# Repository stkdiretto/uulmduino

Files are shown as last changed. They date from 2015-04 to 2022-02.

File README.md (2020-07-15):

# uulmduino

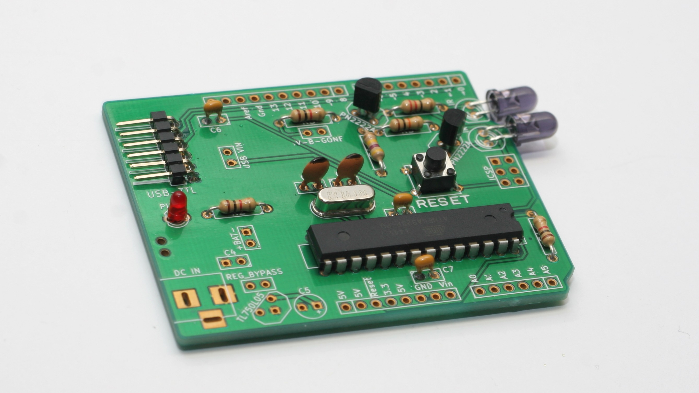
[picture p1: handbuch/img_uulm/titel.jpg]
Yay!


Eine Mischung aus Arduino (besser gesagt dem [Diavolino von Evil Mad Scientist Labs](http://www.evilmadscientist.com/2010/diavolino/)) und der [TV-B-Gone-Version von Ken Shirriff](https://github.com/shirriff/Arduino-TV-B-Gone). Auf Basis des Diavolino und mit Hilfe des [Sparkfun Inventors' Kit](https://www.sparkfun.com/products/12060) von der [Arbeitsgruppe WissenSchaffer](http://www.uni-ulm.de/in/fakultaet/studieninteressierte/wissenschaffer.html) entwickelt für den Girls'Day 2015 an der Uni Ulm.

## Handbuch bauen

Das Handbuch ist [im Ordner "handbuch"](handbuch/) und liegt als Markdown vor. Es kann mit Pandoc nach PDF exportiert werden:

`pandoc anleitung.md -o anleitung.pdf --latex-engine=xelatex --variable geometry="a5paper" --variable mainfont="Droid Sans"`

Wer das Projekt nachmachen möchte, findet im handbuch-Ordner auch eine skizzenhafte Anleitung, was hinter den Kulissen passieren muss. Pull-Requests zur Verbesserung sind gerne gesehen!

## Dankeschöns

 * Leiterplattentechnik der Uni Ulm für die gute Beratung und die Platinenfertigung
 * Maria Aufheimer, Robien Baldrich, Dominic Meißner, David-1 Schmid für Bugfixing und Input
 * Juliane Wessalowski für den Betatest
 * Alle Beitragenden, deren Basismaterial unter Freier Lizenz wir verwenden durften!

## Changelog
 * 2015-04-22 Erste Version
 * 2015-04-22 Übersetzte Experimente aus dem SIK hinzugefügt
 * 2015-04-22 KiCad-Quellen hinzugefuegt
 * 2015-08-26 Revision 2 mit umfangreicherererer KiCad-Quellenlage und einigen gefixten Fehlern. Noch nicht praxiserprobt!
 * 2015-11-16 Fehler in rev2 vermerkt und [BOM](bom.md) hinzugefügt, Fehler im Handbuch korrigiert
 * 2016-04-12 Erster Aufschlag einer [Anleitung für KursleiterInnen](handbuch/fuer%20kursleiter_innen.md)

## Bekannte Fehler (Revision 2)
 * Bei allen Transistoren sind B und E vertauscht :(

## Bekannte Fehler (Revision 1, veraltet)
 * IR-Sender ist auf dem Board mit Pin 9 verbunden → Sollte Pin 10 sein (Fixed in rev2)
 * DC-In-Buchse hat Masse auf dem mittleren Pin, sollte eigentlich andersherum sein (Fixed in rev2)
 * Bohrlöcher für die Zugentlastung der Batteriekastenzuleitungen sind zu klein (Fixed in rev2)
 * Beschriftungen könnten besser sein (Sort of fixed in rev2)
 * KiCad-Files sind sehr unorganisiert (Sort of fixed in rev2)

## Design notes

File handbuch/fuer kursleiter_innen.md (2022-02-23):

# uulmduino – Handbuch für Kursleiter_innen

Titelbild

Ein Free-Hardware+Software-Projekt nicht nur für Jugendliche.  

Basierend auf dem Diavolino von Evil Mad Scientist  
http://www.evilmadscientist.com/go/diavolino

Bausatzversion 2
Handbuch für Kursleiter_innen, passend zum Handbuch v. 0.21, 2015-11-25

# Vorbereitung

Cool, dass Du unser Projekt bei Dir umsetzen möchtest! :) Für die Umsetzung bei Dir brauchst Du die folgenden Dinge:

 * Platinen für alle Teilnehmer_innen, und am besten mindestens noch eine für Dich selbst zum vorher selbst ausprobieren. Falls Du die nicht selber mit den Design Files in diesem Repository herstellen willst, kannst Du auch welche von uns bekommen!
 * Für jedes Exemplar die notwendigen Bauteile, die [in der BOM aufgelistet sind](../BOM.md)
 * Ausreichend viele Lötarbeitsplätze (idealerweise pro Teilnehmer_in, ggf. auch ein Platz pro zwei Personen) mit
  * Lötkolben
  * Lötzinn
  * Entlötpumpe
  * Falls gewünscht: Flussmittel
  * Ausreichend Beleuchtung
  * ggf. Holzbrettchen als Lötunterlage
 * FTDI-232-Adapter zum Programmieren, samt USB-Kabel. Die gibt es in „Original“ für je 15 EUR bei Watterott, exp-tech und Co., oder als Clones für ca. 5 EUR von ebay – bei letzteren aber mit unklarer Funktionsgarantie. Im Idealfall hast Du ebensoviele FTDI-Adapter wie Teilnehmer\*innen.
 * Einen In-System-Programmer oder zwei klassische Arduinos, um die Atmegas vorher zu flashen
 * Ausreichend viele Rechner/Laptops mit der Arduino IDE, den Beispielprogrammen von Sparkfun und dem TV-B-Gone-Sketch
  * Falls Du Windows verwendest, musst du vorher den FTDI-Treiber installieren

## Atmegas flashen

*Bevor* die Bausätze verlötet werden, solltest du auf allen Microcontrollern den Arduino-Bootloader installieren. 

Wenn du ohnehin „klassische“ Arduinos herumliegen hast, kannst du einen davon als ISP verwenden, ihn per Drahtbrücken mit einem zweiten Arduino-Board verbinden und dort die „frischen“ Chips sockeln und flashen. Klingt kompliziert, geht aber recht simpel. [Eine Anleitung findest du hier](https://www.arduino.cc/en/Tutorial/ArduinoISP). Falls du keinen Arduino mit Wechselsockel hast, in den du die frischen Chips einsetzen kannst, geht das auch auf einem Steckbrett (siehe Anleitung).

Die andere (ggf. bei vielen zu flashenden Controllern etwas schnellere) Variante ist ein klassischer ISP. Der [usbasp](http://www.fischl.de/usbasp/) ist günstig zu haben, als China-Clon von ebay sogar für deutlich unter 5 EUR. In dem Fall würde ich dem Erfinder dann aber noch per PayPal ein paar Euro in den Hut werfen wollen ;)  
Mit dem usbasp lässt sich mittels 10-auf-6-Pin-Adapterkabel der Controller auch flashen, wenn er schon verlötet ist – dazu einfach die sechspolige Headerleiste auf der Platine bestücken, oder einen [Pogo-Pin-Adapter](http://www.exp-tech.de/isp-pogo-adapter) auf die Kontakte aufdrücken. Empfehlenswerter ist aber, die Controller vorher in ein passendes Evaluationsboard zu stecken und zu flashen – früher war das Pollin-Evaluationsboard für 15 EUR das Mittel der Wahl, heutzutage gibt es mit dem [aTeVaL](https://www.ehajo.de/aTeVaL-v2.0-Microchip-AVR-Evaluationsboard/200.018) für ca 30 EUR jedoch eine praktischere Lösung, bei der der USB-ISP-Adapter bereits integriert ist.

Auf [Sparkfun ist der Flash-Prozess mit einem USB-Adapter](https://learn.sparkfun.com/tutorials/installing-an-arduino-bootloader) ebenfalls gut beschrieben.

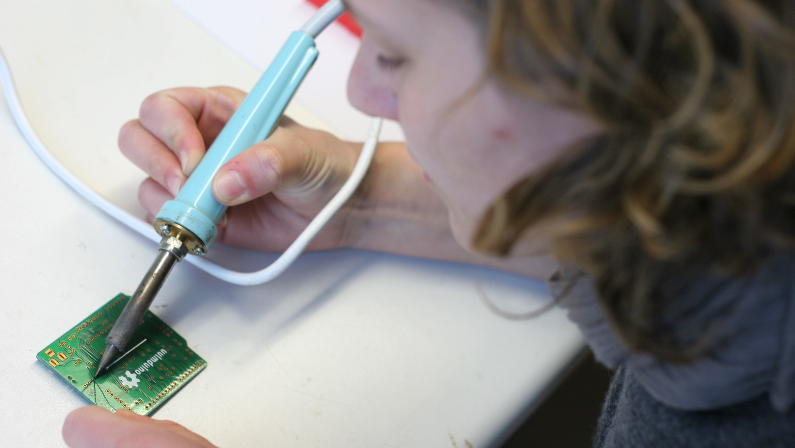
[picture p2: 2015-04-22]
handbuch/img_uulm/loeten.jpg

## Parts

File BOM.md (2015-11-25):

# Bill of Materials

| Name | Anzahl | Reichelt-Artikelnummer | Preis Reichelt | Gesamtpreis |
|---|---|---|---|---|
| Atmega 328 PU | 1 | ATMEGA 328P-PU | 3,15 | 3,15 |
| LED 3mm rot | 1 | LED 3MM ST RT | 0,09 | 0,09 |
| Quarz 16 MHz | 1 | 16,0000-HC49U-S | 0,21 | 0,21 |
| Header, 6 Pins | 1 | MPE 094-1-006 | 0,23 | 0,23 |
| Batteriekasten 3 AAA | 1 für Batteriebetrieb | HALTER 3XAAAK | 0,72 | 0,72 |
| Widerstand 10kΩ | 1 | METALL 10,0K | 0,082 | 0,082 |
| Widerstand 22Ω | 1 | 1/4W 22 | 0,103 | 0,103 |
| Widerstand 470kΩ | 1 | 1/4W 470K | 0,103 | 0,103 |
| Reset-Taster | 1 | TASTER 9302 | 0,11 | 0,11 |
| Transistor PN 2222 A | 2 | PN 2222A | 0,08 | 0,16 |
| IR-LED LD 271 | 2 | LD 271 | 0,42 | 0,84 |
| Keramikkondensator 18P RM 2,5mm  | 2 | KERKO 18P | 0,06 | 0,12 |
| Keramikkondensator 100N RM 2,5mm | 3 | X7R-2,5 100N | 0,05 | 0,15 |
| Header, 8 Pins | 3 | MPE 094-1-008 | 0,23 | 0,69 |
| Widerstand 1kΩ | 3 | 1/4W 1,0K | 0,103 | 0,309 |
| Jumper, RM 2,5mm | 2 | JUMPER 2,54 RT | 0,05 | 0,10 |

Zusätzlich pro 6 Platinen:
 * SL 1X40W 2,54 (0,32 EUR)

Zusätzlich pro 25 Platinen:
 * MPE 087-1-050 (0,87 EUR)

**Batterien nicht vergessen! (3 AAA)** z.B. GP AL40 AAA, 40 Stück für 10,60 EUR. Akkus funktionieren leider nicht.

# Gesamt

7,17 EUR plus 1/6 0,32 EUR plus 1/25 0,87 EUR plus 3/40 10,60 EUR ;) – Platinenkosten etwa 1,25 EUR  
Macht gesamt rund **8,06 EUR** bzw. **9,31 EUR** inkl. Platine.

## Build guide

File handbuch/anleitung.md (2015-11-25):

# uulmduino

Titelbild

Ein Free-Hardware+Software-Projekt für den Girls'Day 2015 an der Universität Ulm.  

Basierend auf dem Diavolino von Evil Mad Scientist  
http://www.evilmadscientist.com/go/diavolino

Bausatzversion 2
Handbuch v. 0.21, 2015-11-25

# Was ist was?

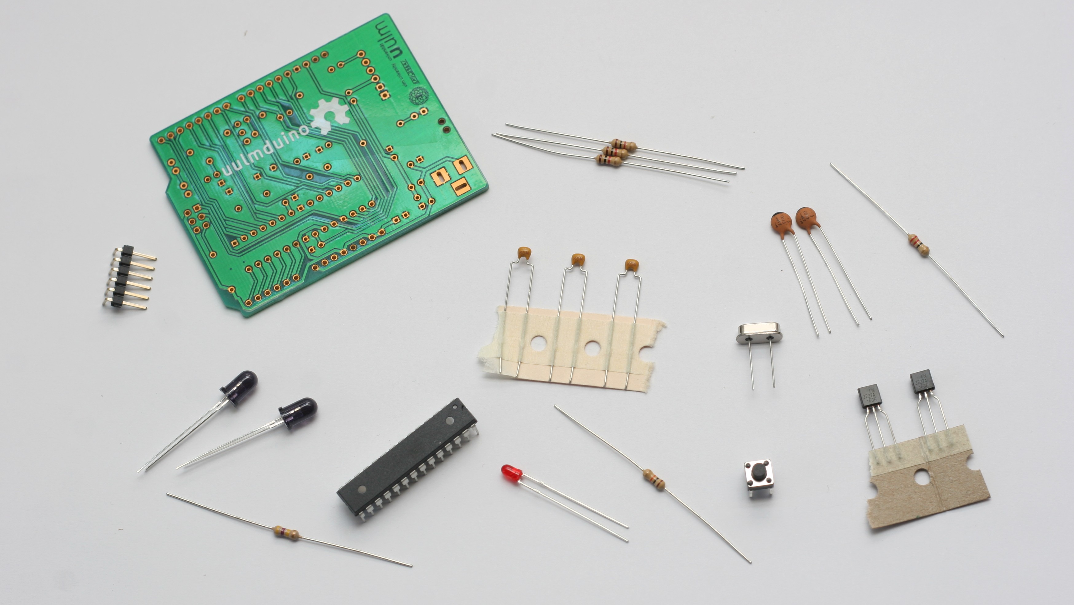
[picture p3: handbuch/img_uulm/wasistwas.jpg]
Was ist was?


 1. Platine
 2. Kurzanleitung (nicht abgebildet)
 3. 1kΩ-Widerstände,¼ Watt (3 Stück)
 4. 10kΩ-Widerstand, ¼ Watt
 5. 18pF-Kondensatoren (2 Stück) (Schwarzer Streifen!)
 6. 1µF-Kondensatoren (3 Stück)
 7. Mikroschalter
 8. LED
 9. Quarz
 10. Header
 11. Microcontroller
 12. 22Ω-Widerstand, ¼ Watt
 13. 470kΩ-Widerstand, ¼ Watt
 14. Transistoren PN2222A (2 Stück)
 15. Infrarot-LEDs LD271 (2 Stück)
 16. Batteriekasten 3×AAA (nicht abgebildet)
 17. Header für Arduino-kompatible Shields (nicht abgebildet)

# Optional für zuhause

Diese Teile reichen vollkommen, um einen Universal-Fernsehausknipser (TV-B-Gone) für unterwegs zu bauen. Für die Programmierung und weitere Experimente in diesem Handbuch sind weitere Teile nötig, die wir Dir aufgrund der Kosten leider nicht mitgeben können. Du kannst sie dir aber für wenig Geld online kaufen, falls du zuhause weitermachen möchtest!

## Für die Programmierung…

Der uulmduino ist Arduino-kompatibel, benötigt aber eine Programmierschnittstelle.

### Ein USB-TTL-Kabel

…mit dem FTDI-chip TTL-232R oder einem vergleichbaren Modell. Das ist ein „intelligentes“ Adapterkabel mit einer eingebauten USB-Schnittstelle. Eine Seite wird in Deinen USB-Port eingesteckt, die andere in den uulmduino. Das Kabel ermöglicht Dir, den uulmduino mit der Arduino-Entwicklungsumgebung zu programmieren (http://arduino.cc/).
Alternativ kann uulmduino auch mittels eines AVR-ISP-Programmierers programmiert werden, zum Beispiel dem USBtinyISP.

### Computer, Internetzugang, USB-Port…

Alle Software, die Du benötigen wirst, ist kostenlos erhältlich. Du brauchst nur einen nicht allzu antiquierten Rechner (Mac, Windows oder Linux) und einen Internetzugang, um die Arduino-Software herunterzuladen.

# Tipps fürs Löten

Die meisten Probleme mit Lötbausätzen sind auf unzureichende Lötstellen zurückzuführen. Bevor wir fortfahren, gibt es hier einen Mini-Lötkurs, mit unserer empfohlenen Vorgehensweise, um die einzelnen Bauteile in die Platine einzulöten. Sie ist auf die meisten Teile dieses Bausatzes anwendbar.

## Bauteile auf die Platine einlöten

 0. Biege die Anschlussdrähte der Teile zurecht, falls nötig. (Zum Beispiel diese Widerstände).
 1. Setze jedes Bauteil von oben her an der vorgesehenen Stelle in die Platine ein. Drücke es bündig an die Platine an (Beachte, dass einige Teile in eine bestimmte Richtung eingesetzt werden müssen – zum Beispiel der Chip und die LED)
 2. Falls das Bauteil flexible Anschlussdrähte hat, biege die Drähte vorsichtig nach außen, bis zu einem Winkel von etwa 45°. Das hält das Bautel an seinem Platz fest, während Du es festlötest.
 3. Löte von der Rückseite her einen Anschlussdraht nach dem anderen an die Platine an.
  * Die Lötspitze muss glänzend (verzinnt) sein. Falls sie das nicht ist, schmelze ein wenig frisches Lötzinn an der Spitze an und wische sie auf einem feuchten Schwamm sauber.
  * Halte das Lötzinn an die Verbindung, die Du verlöten möchtest.
  * Halte den Lötkolben für etwa eine Sekunde an die Lötstelle und das Lötzinn. Zähle einfach laut mit: „Eintausendeins“.
  * Das Lötzinn sollte an die Lötstelle anschmelzen und eine glänzende, etwas feucht aussehende Lötstelle hinterlassen. Falls nicht, lass' sie abkühlen und versuche es noch einmal.
 4. Falls das Bauteil lange und/oder biegbare Anschlussdrähtchen hat, schneide den auf der Unterseite überstehenden Draht ab – dicht an der Platine, aber nicht so nahe daran, dass Du in die Platine selbst hineinschneidest.

 1. Einsetzen!
 2. Biegen!
 3. Löten!
 4. Kürzen!

## Wir fangen mit den 1kΩ-Widerständen an (#3)

Alle Widerstände sind mit Farbringchen codiert. Die 1kΩ-Widerstände, die wir jetzt brauchen, haben der Reihe nach die Farbe Braun-Schwarz-Rot (und danach ein goldenes Ringchen). Schau genau hin und verwechsle sie nicht mit dem 10kΩ-Widerstand – der hat ein orangenes statt eines roten Ringchens!

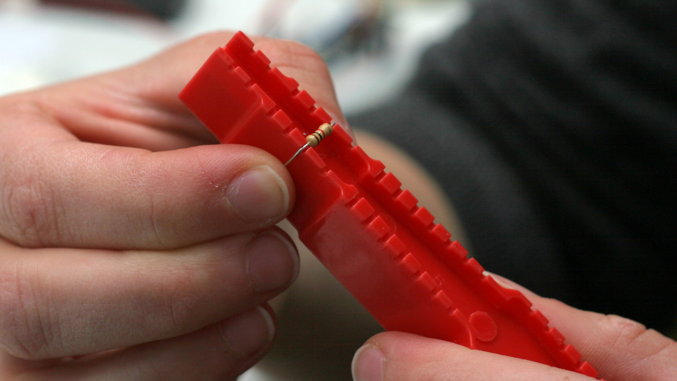
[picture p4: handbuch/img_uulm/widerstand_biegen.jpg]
Zuerst biegst Du die Anschlussdrähte zurecht. Entweder mit einer Biegelehre, oder frei Hand.


Stecke den Widerstand an die mit **R2**, **R3** und **R5** markierten Stellen in die Anschlusslöcher. Wie herum du ihn einsetzt, ist egal – ein Widerstand funktioniert in beide Richtungen.

Plan auf die Platine aufdrücken…

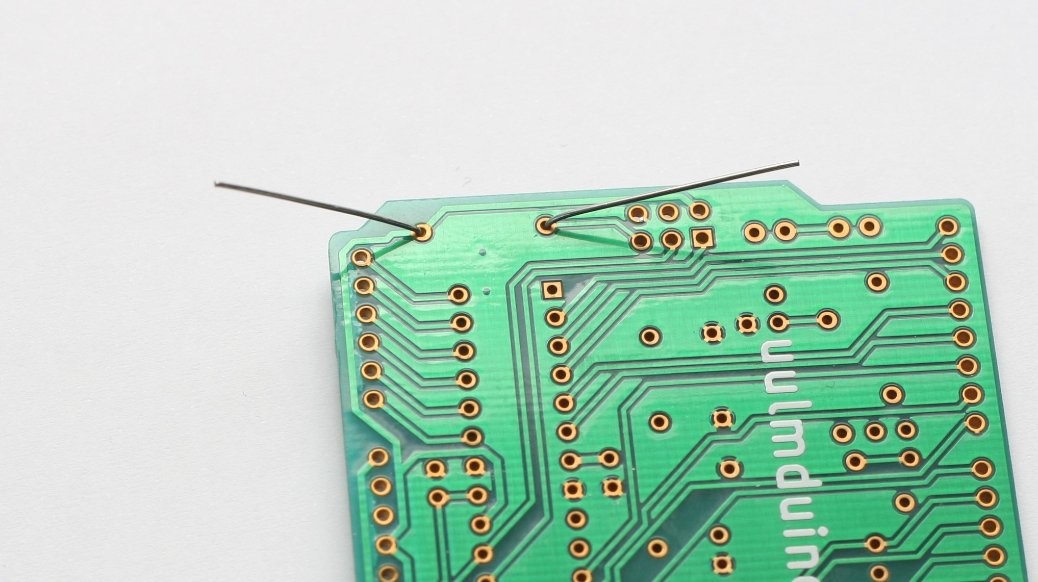
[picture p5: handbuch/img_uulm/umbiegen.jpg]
…und die Anschlussdrähte auf der Unterseite auseinanderbiegen.


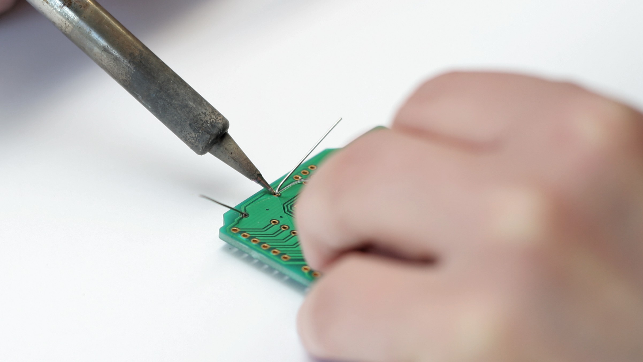
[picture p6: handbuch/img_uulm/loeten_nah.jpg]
Festlöten.


Überprüfe die Lötstellen. Sie sollten glänzend aussehen, und das Lötpad (auf der Platine) und die Beinchen ganz umfließen.

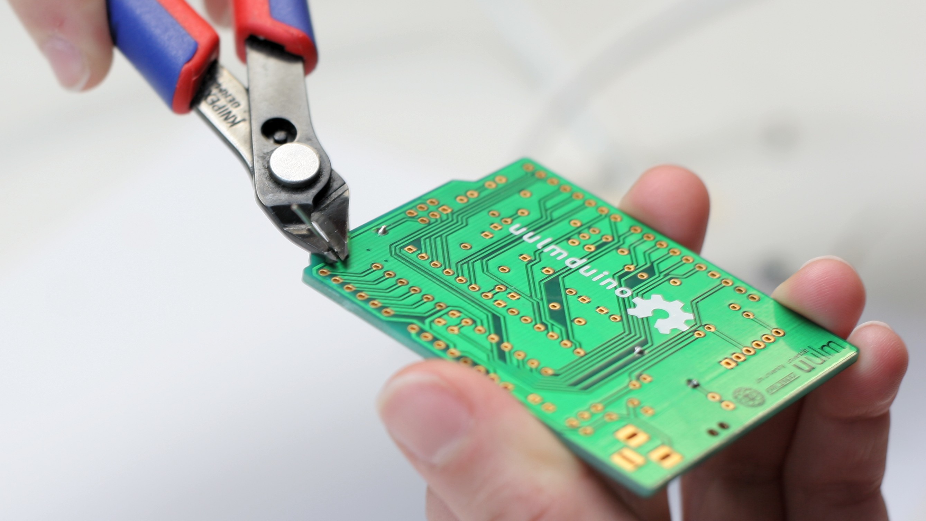
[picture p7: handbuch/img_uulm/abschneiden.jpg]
Überstehende Drähtchen abschneiden.


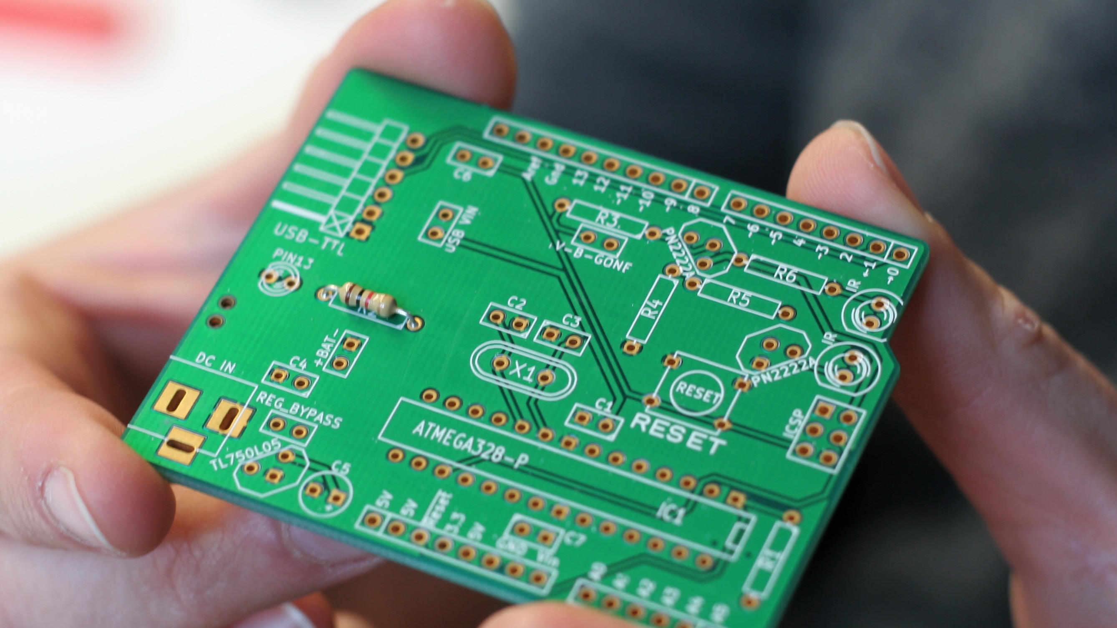
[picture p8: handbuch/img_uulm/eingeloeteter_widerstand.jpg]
Richtig festgelöteter Widerstand.


## Als nächstes: Der 10kΩ-Widerstand, #4.

Das ist nun der Widerstand mit Braun-Schwarz-Orangen Ringchen. Verlöte diesen Widerstand auf dieselbe Weise an der Stelle, an der **R1** auf der Platine steht.

## 18pF-Kondensatoren, #5.

Die zwei 18pF-Kondensatoren im Bausatz sind mit einem schwarzen Strich versehen.

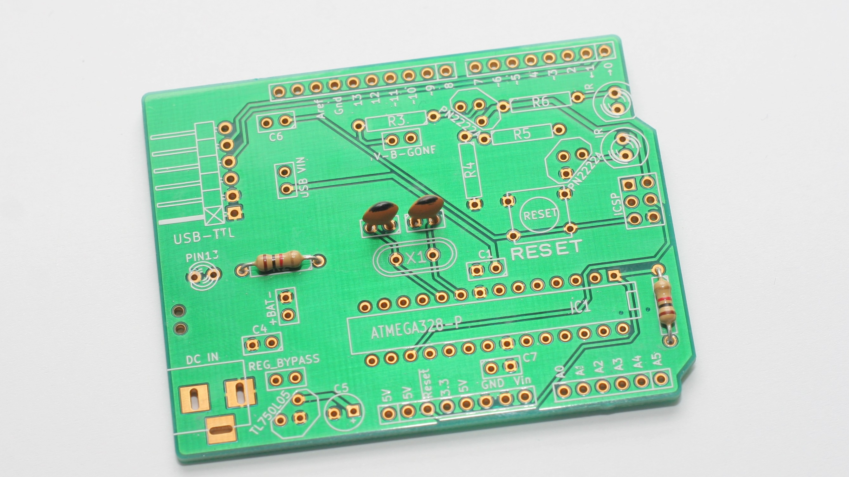
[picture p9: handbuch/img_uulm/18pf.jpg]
Löte die beiden Kondensatoren an die Stellen **C2** und **C3**.


Biege die Anschlussdrähte auf der Platinenunterseite auseinander, löte sie dann fest und kürze die Enden.

## 0,1µF-Kondensatoren, #6.

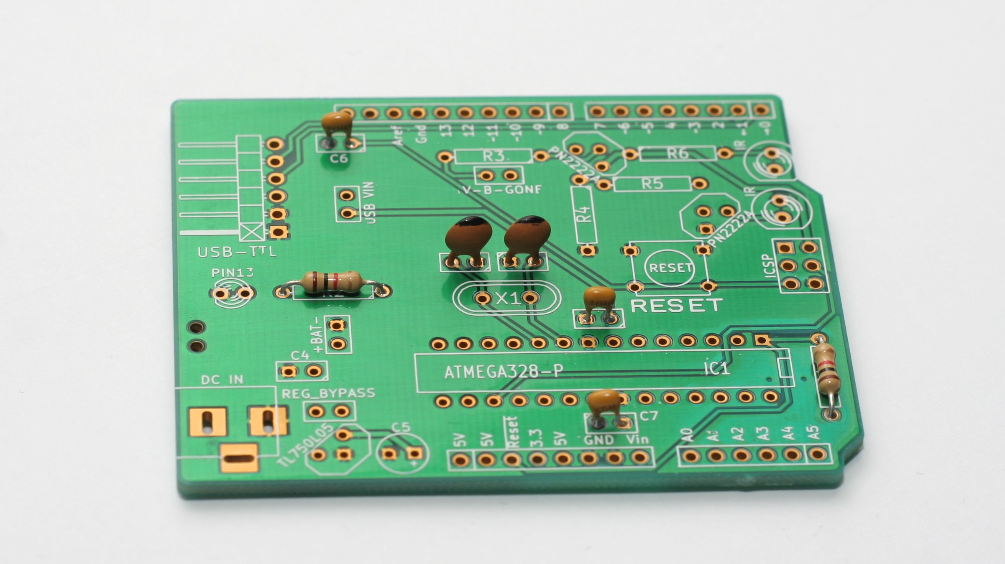
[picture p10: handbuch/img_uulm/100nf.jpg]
Von diesen Kondensatoren gibt es drei Stück. Sie gehören an die Stellen **C1**, **C6** und **C7**.


Löte die drei Kondensatoren an diesen Stellen fest. Biege, verlöte und kürze die Anschlussdrähte wie zuvor beschrieben!

## Mikroschalter, #7.

Stecke den Schalter an dieser Stelle in die Platine.
Unter Umständen *schnappt* er richtiggehend ein.

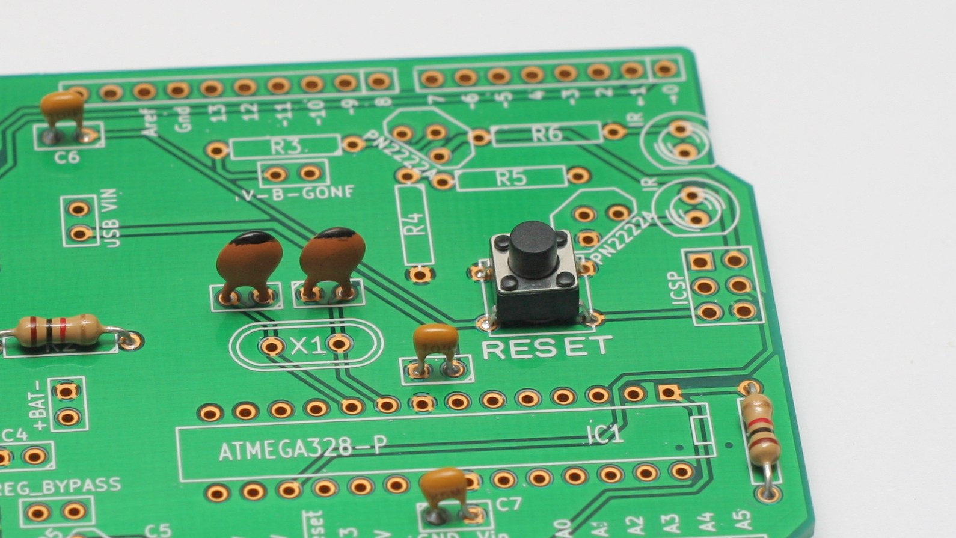
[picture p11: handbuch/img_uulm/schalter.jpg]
Wichtig ist, dass die „Klauen“ auf der Unterseite nach rechts und links zeigen, also zu den schmalen Seiten der Platine. Andersherum funktioniert der Bausatz später nicht.


Du kannst die Anschlusspins nach innen biegen, damit der Schalter beim Löten nicht herausfällt. Die Anschlusspins sind kurz und müssen normalerweise nach dem Löten nicht gekürzt werden.

## LED, #8.

3mm diffus-rote LED. Beachte die unterschiedlich langen Anschlussbeinchen: Richtig einsetzen ist wichtig!

Stecke das *kurze Ende* durch das *quadratische Loch* an der Stelle **LED3/PIN13**. Das *kurze Ende* sollte auf der Seite der Zeichnung auf der Platine sein, an der der Kreis abgeflacht ist.

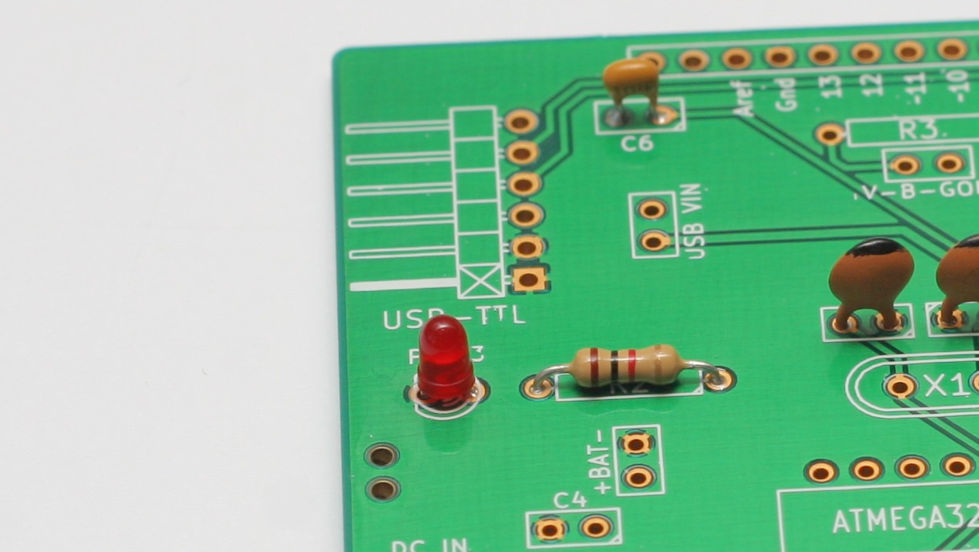
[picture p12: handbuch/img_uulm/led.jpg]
Drücke die LED dann wie gewohnt plan auf die Platine, löte fest und kürze die Beinchen.


## 16-MHz-Quarzkristall, #9.

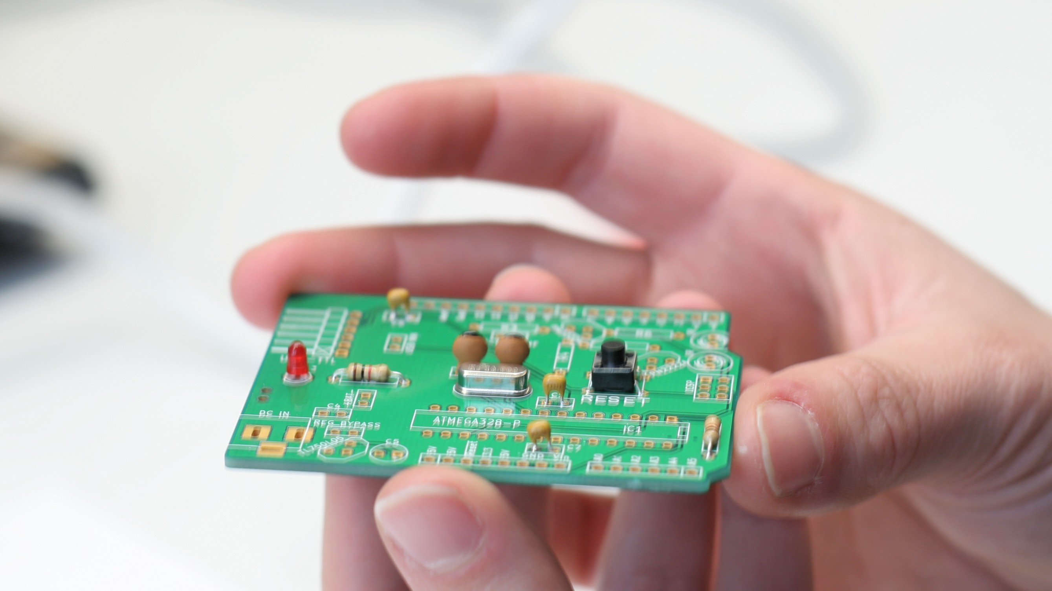
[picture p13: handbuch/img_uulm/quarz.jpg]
Ein glänzendes Döschen mit zwei Beinchen, es gehört an die Position **X1**.


Wie herum Du es einsetzt, ist egal.

Dann wieder wie gewohnt plandrücken, löten und kürzen.

## TTL-Programmieranschluss #10.

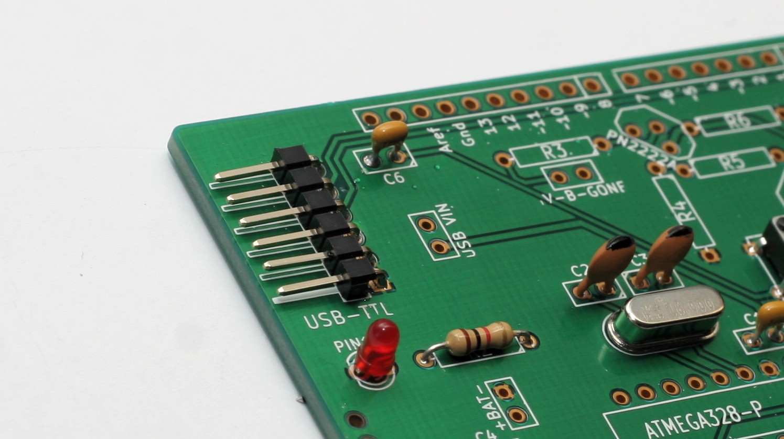
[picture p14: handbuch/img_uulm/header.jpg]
Das ist der Anschluss für das USB-TTL-Kabel.


Setze den abgewinkelten TTL-Programmieranschluss (mit den sechs Pins) in die Platine ein, damit Du siehst, wie er hineingehört.

Die Anschlussbeinchen lassen sich nicht verbiegen. Löte daher eines der Beinchen von oben her an, um es fürs Verlöten zu fixieren.

Löte die anderen Beinchen von der Rückseite her fest. Die Beinchen müssen nach dem Verlöten nicht gekürzt werden.

## Jetzt kommt der Fernseh-Ausknips-Part

Die Widerstände R3 und R5, die zum Infrarotsender gehören, hattest Du ja schon eingelötet. Zwei fehlen aber noch.

### Widerstand 22Ω

Auch diesen Widerstand findest Du über seine Farbmarkierung. Er hat Rot-Rot-Schwarze Ringchen (und wieder ein goldenes am Ende). Er kommt an die Stelle **R6**

### Widerstand 470kΩ

Und das ist der letzte der Widerstände. Er ist Gelb-Lila-Gelb markiert und kommt an die Position **R4**.

### Die Transistoren

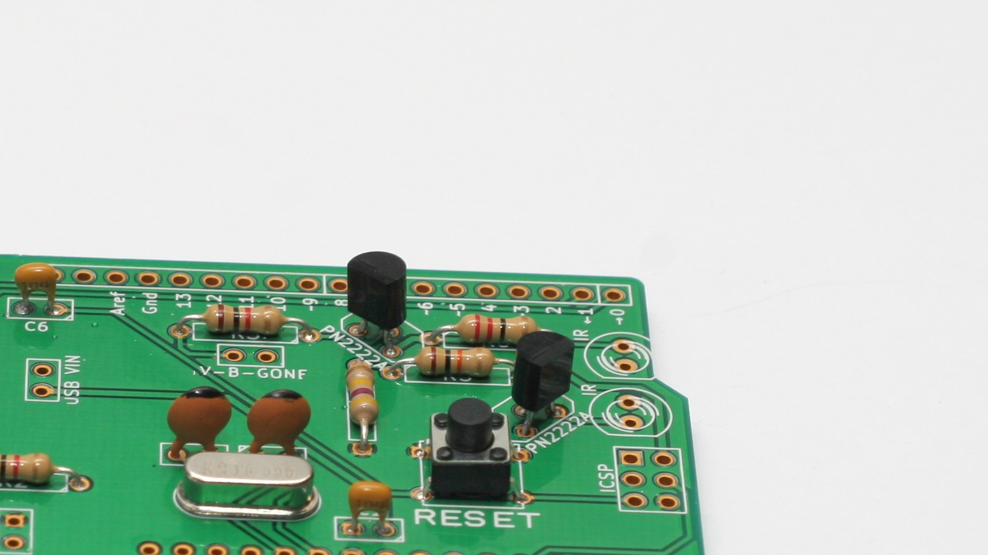
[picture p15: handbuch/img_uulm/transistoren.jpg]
Die Transistoren müssen genauso eingesetzt werden, wie es der jeweilige Umriss auf der Platine anzeigt. Dazu musst du die äußeren Beinchen ein wenig auseinander- und das mittlere Beinchen in Richtung des „Bauchs“ biegen.


Die Transistoren sorgen dafür, dass aus dem schwachen Signal aus dem Microcontroller richtig viel Power wird – damit der Ausknipser auch auf weitere Entfernungen funktioniert!
Schau Dir das Gehäuse gut an: Es ist auf einer Seite bauchig, und auf der anderen Seite abgeflacht.
Auf der Platine findest du eine ähnliche Markierung, mit der Bezeichnung **PN2222A**.

Lasse ein paar Millimeter Abstand zur Platine (das geht fast schon automatisch, wegen der herausgebogenen Beinchen), biege die Beinchen unten wie gewohnt auseinander, biege sie um, löte sie fest und knipse sie ab!

### Infrarot-LEDs

Diese LEDs leuchten für uns Menschen unsichtbar, aber ein Fernseher kann dieses Infrarotlicht empfangen. Auch wenn wir das Licht aus den LEDs nicht sehen können, ist es ganz schön hell – Du solltest deshalb nicht in sie hineinsehen, während dein uulmduino Fernseher auszuschalten versucht.

Sie kommen an die Stelle, die mit **IR** bezeichnet ist. Das kürzere der Beinchen kommt wieder in das Loch auf der Seite, an der der Kreis auf der Platine abgeflacht ist. Das Gehäuse der LED ist an dieser Stelle ebenfalls abgeflacht – das hilft Dir bei der Orientierung!

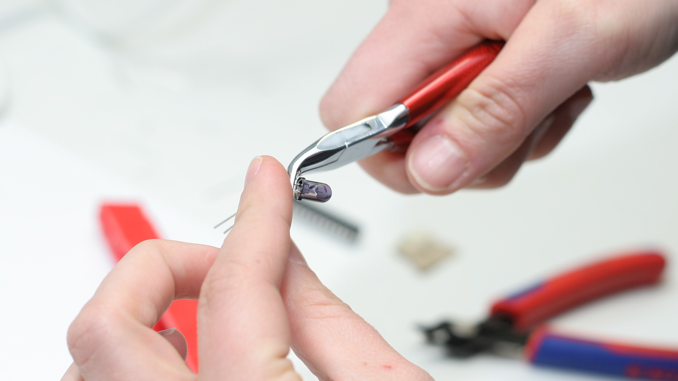
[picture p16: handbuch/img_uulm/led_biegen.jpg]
Damit der uulmduino später auch „nach vorne“ sendet, kannst Du die LEDs vor dem Löten umbiegen. Entweder direkt auf der Platine, oder Du merkst Dir, wie herum du biegen musst, und nimmst eine Zange. Lieber zweimal schauen und dann richtig biegen! ;)


### Damit Du den uulmduino flexibel benutzen kannst: Eine Steckbrücke

An die mit **TV-B-GONE** beschriftete Stelle kommt wahlweise eine Steckbrücke oder eine Drahtbrücke. Wenn du weißt, dass Du den uulmduino *immer* nur als Fernsehausknipser verwenden möchtest, kannst Du hier auch direkt einen Draht einlöten.

Falls Du zuhause auch noch ein wenig mit der Arduino-Funktionalität des uulmduino experimentieren magst, kannst Du stattdessen eine Steckbrücke einlöten. So kannst Du immer dann einen Jumper auf die Steckbrücke aufsetzen, wenn Du Fernseher ausknipsen magst – und falls Du den Pin 9 (auf dem der Infrarotsender angeschlossen ist) für etwas anderes benutzen magst, kannst du den Jumper wieder abnehmen.

*Wichtig:* Wenn Du eigene Programme mit dem uulmduino verwendest, solltest Du Pin 9 nicht anschalten, solange der Infrarotsender mit Pin 9 verbunden ist. Die Infrarotschaltung ist auf die typischen kurzen Pulse einer Fernbedienung ausgelegt – und so kann sie auch minuten- oder stundenlang betrieben werden. Wenn Du sie jedoch *dauerhaft* anschaltest, können die LEDs irgendwann durchbrennen.

## Zeit für den Microcontroller.

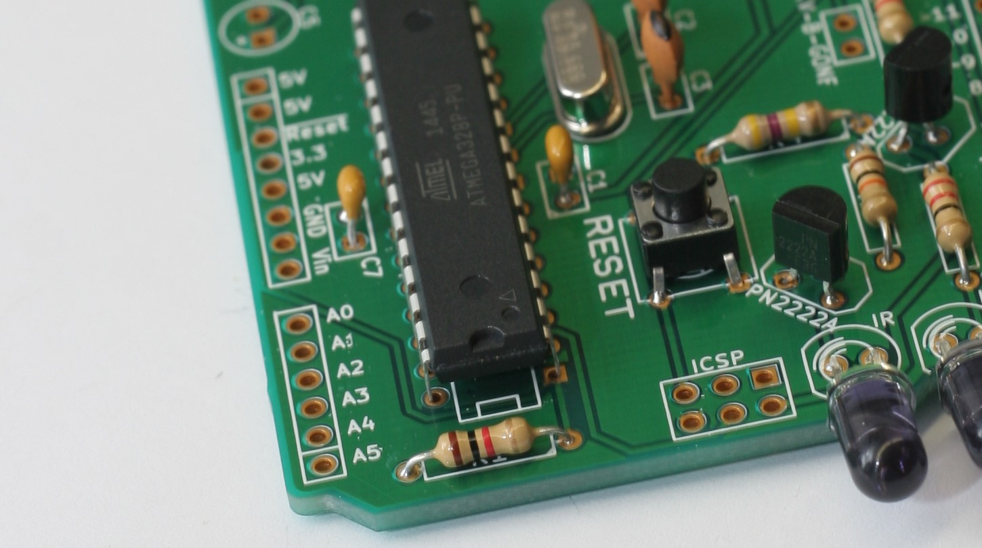
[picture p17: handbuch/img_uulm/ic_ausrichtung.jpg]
Die richtige Ausrichtung ist wichtig. Du musst den Chip so einsetzen, dass die halbmondförmige Kerbe an der einen Seite des Chips mit der Halbmondmarkierung auf der Platine übereinstimmt.


### Setze den Chip vorsichtig ein.

Überprüfe zur Sicherheit nochmal, ob Du ihn richtigherum eingesetzt hast.

Der Chip sollte sich mühelos durch die Löcher stecken lassen. Falls nötig, biege die Beinchen des Chips vorsichtig so, dass sie gerade nach unten zeigen. Biege sie nicht einzeln von Hand, sondern biege alle Beinchen einer Seite gleichzeitig zurecht, indem du den Chip seitlich auf eine harte, ebene Unterlage drückst.

Drehe die Platine um und löte den Chip fest – an allen 28 Beinchen. 

*Tip:* Du kannst die Beinchen an den Ecken vorsichtig umbiegen, damit der Chip festsitzt, während Du ihn festlötest.

## Damit ist die Platine eigentlich schon fast fertig!

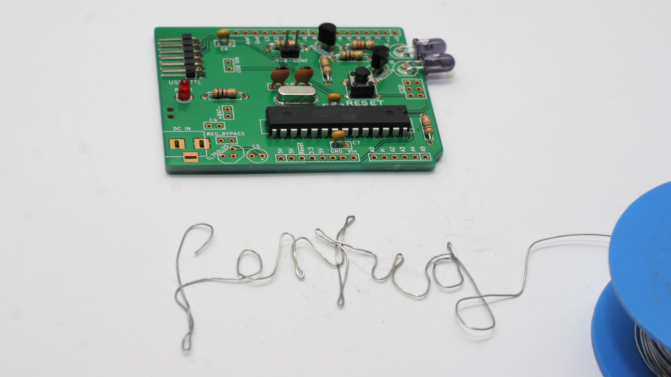
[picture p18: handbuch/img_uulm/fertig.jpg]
Fast fertig – nur die Batteriebox und die Header zum Experimentieren fehlen noch.


Wir brauchen aber noch eine Spannungsquelle, damit Du den uulmduino auch betreiben kannst.

Der Chip benötigt 4,5–5,5 V Gleichstrom, wenn er mit 16 MHz läuft. Du kannst ihn mittels dreier AA- oder AAA-Alkaline-Batterien mit 4,5V versorgen.

*Anmerkung:* Akkus reichen in der Regel nicht aus, um die erforderliche Spannung zu liefern.

Der Diavolino passt wunderbar auf einen Batteriekasten.

Um das Ganze noch praktischer zu machen, kannst du die Anschlussdrähte auf einige Zentimeter kürzen (und die Enden abisolieren), um weniger Kabelsalat zu haben.

Du kannst ihn auch mit einem Stück doppelseitigem Schaumstoffklebeband direkt auf den Kasten aufkleben.

Egal ob du die Leitungen nun kürzt oder nicht, so werden sie festgemacht: Du lötest den roten Draht in das Loch mit **+** und den schwarzen Draht in das mit **–** markierte Loch.

## Zuletzt: Verbindungsheader hinzufügen

Diese Header sind optionale Extras, wenn Du Arduino-kompatible „Shield“-Platinen auf den Diavolino aufzustecken möchtest. Stecke sie wie hier gezeigt durch die Löcher und löte sie plan auf der Platine fest.

Zwei Header mit 6 Beinchen, zwei mit 8 Beinchen.

Anmerkungen:
 1. Die Beinchen können nicht wirklich gut verbogen werden, um die Header an Ort und Stelle zu halten. Es ist einfacher, sie mit Kreppband zu fixieren – oder die gesamte Platine umzudrehen, so dass sie auf den Headern liegt.
 2. Am besten lötest du zuerst nur jeweils ein Beinchen fest, damit Du prüfen kannst, ob die Header plan und gerade sitzen, bevor Du sie endgültig verlötest.
 3. Die Beinchen sind kurz genug, so dass Du sie in der Regel nicht kürzen musst.

# Experimentieren!

In diesem Kapitel haben wir einige Experimente zusammengestellt, die wir dem freien Sparkfun Inventors' Kit (SIK) entnommen haben. Du brauchst dafür nur ein Steckbrett („Breadboard“), einige Verbindungskabel („Jumperkabel“) und elektronische Kleinteile. Wir können Dir die zwar leider nicht mit nach Hause geben, Du kannst sie aber für wenig Geld nachkaufen – entweder im Elektronikladen, oder in diversen Onlineshops oder im Onlineversteigerungshaus. Wenn die Teile aus Fernost kommen, sind sie meistens viel billiger, brauchen aber sehr lange für den Versand.

Das SIK findest Du online auf https://www.sparkfun.com/products/12060 – dort findest Du auch das komplette SIK-Handbuch und den dazugehörigen Code mit allen möglichen Experimenten, die Du mit dem uulmduino, Breadboard und einigen Kleinteilen selber durchführen kannst!

## Das USB-TTL-Kabel anschließen

Auf der Platine steht ein „USB-TTL“ – an diese Seite kommt die mit „GND“ beschriftete Seite deines Kabels. Falls Du ein Kabel mit Farbcodierung hast: Schwarz kommt nach unten (in Richtung der „USB-TTL“-Beschriftung), Grün nach oben.

Stecke die andere Seite des Kabels in den USB-Port Deines Computers. Die meisten Betriebssysteme (vor allem die meisten GNU/Linux- und Mac-Betriebssysteme) unterstützen das FTDI232-Kabel von Haus aus. Bei anderen Betriebssystemen musst Du gegebenenfalls noch einen Treiber installieren. Auf www.sparkfun.com/FTDI findest Du eine Anleitung hierfür.

## Öffne die Arduino IDE

Öffne die freie Arduino-IDE-Software auf Deinem Computer, die Du von arduino.cc heruntergeladen hast. Spiele ein wenig herum und mache Dich mit der Benutzeroberfläche vertraut. Wir fangen jetzt noch nicht direkt mit der Programmierung an, das ist nur eine Einführung. In diesem Schritt stellen wir die IDE so ein, dass sie Deinen uulmduino erkennt.

## Wähle Dein Board aus: Arduino Uno

Dein uulmduino und der Arduino UNO sind baugleich, aber Du findest den uulmduino nicht in der Arduino-Software. Wähle stattdessen „Arduino UNO“ aus.

## Wähle Deine serielle Schnittstelle

Wähle die serielle Schnittstelle, an der der uulmduino angeschlossen ist, aus dem *Tools | Serial Port*-Menü aus. Um die passende Schnittstelle herauszufinden, kannst Du das USB-TTL-Kabel ausstecken und das Menü nochmals öffnen – der Eintrag, der nun verschwunden ist, sollte der uulmduino sein. Verbinde das Board wieder und wähle diese Schnittstelle aus.

Auf dem Mac sollte diese */dev/tty.usbmodem* oder */dev/tty.usbserial* im Namen haben. Unter Windows dürfte das in der Regel COM3 oder höher sein. Beim Girls'Day haben wir Dir bereits alles voreingestellt.

## Lade den Arduino-Code herunter (den wir für die Schaltkreise dieses Handbuchs verwenden)

Für den Girls'Day haben wir Dir bereits alles auf unseren Rechnern eingerichtet.

Falls Du zuhause weiter experimentieren magst, kannst Du die Originalcodes des SIK verwenden – die es aber leider nur auf Englisch gibt. Im SIK-Handbuch auf https://www.sparkfun.com/products/12060 findest Du den Link und eine Anleitung dafür.

## Erste Schritte mit Schaltkreisen

So sieht Dein Steckbrett aus. Abbildung nach dem SIK, http://creativecommons.org/by-sa/3.0/

Und so funktioniert das alles innendrin. Abbildung nach dem SIK, http://creativecommons.org/by-sa/3.0/

### Was ist ein elektrischer Schaltkreis?

Ein Schaltkreis ist ein elektrischer Kreis mit einem Start- und einem Endpunkt – mit einer beliebigen Anzahl von Bauteilen dazwischen. In einem Schaltkreis können Widerstände, Dioden, Spulen, Sensoren in allen Größen und Formen, Motoren und beliebige andere aus hunderttausenden weiteren Bauteilen vorkommen.

Man unterscheidet üblicherweise drei Arten von Schaltkreisen: Analoge, digitale und hybride Schaltkreise. In diesem Handbuch wirst Du alle drei Arten kennenlernen und ausprobieren.

### Die Welt läuft mit Schaltkreisen:

Egal wohin Du siehst, wirst Du Schaltkreise finden. Das Handy in Deiner Tasche; der Computer, der die Abgasregelung Deines Autos steuert, deine Videospielkonsole – all diese Geräte sind bis zum Rand voller Schaltkreise. In diesem Handbuch wirst Du mit einigen einfachen Schaltungen experimentieren und die Kurzfassung der Welt der eingebetteten Elektronik kennenlernen.

### Einfache und komplexe Schaltungen

Mit diesem Handbuch wirst Du hauptsächlich einfache Schaltungen erforschen – das bedeutet jedoch nicht, dass Du mit diesen einfachen Werkzeugen keine beeindruckenden Dinge anstellen könntest! Wenn Du das SIK durchforscht hast, wirst Du genügend viel über elektronische Schaltungen wissen, um selbständig tolle Projekte zu entwickeln und die Kraft deiner Phantasie zu entfesseln.

## Schaltung 1: Eine LED zum Blinken bringen

Wir verwenden die LED auf dem uulmduino, die mit einem Vorwiderstand (R2 rechts daneben, Du hast ihn selber eingelötet! :D) mit Pin 13 verbunden ist.

### Öffne Deinen ersten Sketch

„Sketch“ heißen die Programme in der Arduino IDE. Wir haben bereits Code vorbereitet, der die LED zum blinken bringt. Du musst ihn nicht abschreiben, sondern Du findest ihn im Sketchbook unter „uulmduino“!

```
/*
  Blinken
  Schaltet eine LED eine Sekunde lang an,
  und dann wieder eine Sekunde lang aus.
  Dieser Beispielcode ist gemeinfrei (public domain).
*/

void setup() {
  // Initialisiere den Digital-Pin als Ausgang
  // Auf den meisten Arduinos ist Pin 13 mit einer LED verbunden
  pinMode(13, OUTPUT);
}

void loop() {
  digitalWrite(13, HIGH); // schalte die LED an
  delay(1000);            // warte eine Sekunde lang
  digitalWrite(13, LOW);  // schalte die LED aus
  delay(1000);            // warte eine Sekunde lang
}
```

Mit einem Klick auf **Prüfen** (der runde Button mit dem Häkchen) kannst du überprüfen, ob Dein Code irgendwelche Fehler hat. Mit **Hochladen** (der Button daneben mit dem Pfeil) lädst Du den Sketch auf Deinen uulmduino.

Spiele mit den Einstellungen: Was passiert, wenn Du die Zahlen hinter `delay` änderst? Kannst Du Muster blinken lassen?

### Wie funktioniert das?

#### pinMode(13, OUTPUT);

Bevor Du irgendeinen der uulmduino-Pins benutzen kannst, musst Du dem uulmduino sagen, ob der Pin ein Eingang (INPUT) oder Ausgang (OUTPUT) ist. Um das zu tun, benutzen wir eine eingebaute Funktion namens pinMode().

#### digitalWrite(13, HIGH);

Wenn Du einen Pin als OUTPUT verwendest, kannst Du ihn auf HIGH setzen („anschalten“, d.h. er gibt 5 Volt aus) und auf LOW („abschalten“, d.h. er gibt 0 Volt aus).

## Was Du sehen solltest:

Du solltest Deine LED nun an- und ausgehen sehen. Falls nicht: Prüfe, ob Du die Schaltung richtig aufgebaut hast.

### Anwendung im echten Leben:

Quasi alle modernen Flachbildfernseher und Monitore haben LEDs, die anzeigen, ob das Gerät an- oder ausgeschaltet ist – oder blinken!

## Schaltung 2: Ein Potentiometer

In dieser Schaltung wirst Du mit einem Potentiometer arbeiten. Potentiometer nennt man auch veränderbare Widerstände. Wenn man es an den äußeren Anschlüssen mit 5 Volt und Masse verbindet, liegt am mittleren Pin eine Spannung zwischen 0 und 5 Volt an – je nachdem, wie das Potentiometer gerade durch Drehen eingestellt ist. Ein Potentiometer ist ein perfektes Beispiel eines veränderbaren Spannungsteilers. Die Spannung teilt sich proportional zum Widerstand zwischen dem mittleren Pin und dem Massepin. Mit dieser Schaltung lernst Du, wie Du mit einem Potentiometer die Helligkeit einer LED regeln kannst.

### Teile:

 * Potentiometer (1×)
 * LED (auf dem uulmduino)
 * Drahtbrücken (5×)

Der Aufbau von Schaltkreis 2. Abbildung nach dem SIK, http://creativecommons.org/by-sa/3.0/

### Digital versus Analog:

DIGITAL heißt **LOW**: Aus, oder 0 Volt – oder **HIGH**: An, oder 5 Volt. ANALOG heißt **0**: 0 Volt bis **1023**: 5 Volt – und alle Werte, die dazwischen liegen! Abbildung aus dem SIK, CC-BY-SA

Wenn Du Deinen uulmduino genauer ansiehst, wird Dir auffallen, dass einige Pins mit „A“ beschriftet sind, und andere einfach nur mit Ziffern. Was ist der Unterschied?

Viele der Geräte, die Du an das Board anschließt – zum Beispiel LEDs und Taster – haben nur zwei mögliche Zustände: An und aus. Man nennt diese Zustände auch „HIGH“ (5 Volt) und „LOW“ (0 Volt). Die Digital-Pins (die nur mit Ziffern) auf dem uulmduino können solche Signale ganz hervorragend entgegennehmen und ausgeben, und können sogar besondere Funktionen übernehmen. Zum Beispiel können sie so tun, als würden sie einen Ausgang dimmen (in dem sie den Ausgang ganz schnell blinken lassen), oder Daten seriell übertragen (indem sie die Daten als Reihe von HIGH- und LOW-Signalen ausgeben).

Es gibt aber eine ganze Menge von Dingen in der Welt, die nicht einfach nur „an“ oder „aus“ sein können. Temperaturen, Kontrollregler usw. haben alle einen durchgehenden Wertebereich zwischen HIGH und LOW. Für solche Situationen hat der uulmduino sechs analoge Eingänge, die eine Eingangsspannung in einen Wert zwischen 0 (0 Volt) und 1023 (5 Volt) übersetzen. Die Analog-Pins sind hervorragend geeignet, um diese Werte aus der „echten Welt“ zu messen und erlauben Dir, an den uulmduino alle möglichen Dinge anzuschließen.

### Codeschnipsel:

#### int sensorValue;

Eine „Variable“ ist ein gespeicherter Wert, dem Du einen Namen gegeben hast. Du musst diese Variable erst einmal einführen (oder „deklarieren“), bevor Du sie benutzen kannst. Hier deklarieren wir eine Variable namens `sensorWert`, vom Typ `int` (Integer, also Ganzzahl). Achte darauf, dass die Groß- und Kleinschreibung der Variablen wichtig ist! Wir benutzen die `analogRead()`-Funktion, um den Wert an einem analogen Eingang einzulesen. `analogRead()` benötigt einen Parameter, den analogen Pin, den Du einlesen möchtest (`sensorPin`), und gibt einen Wert zurück (`sensorWert`), der zwischen 0 (für 0 Volt) und 1023 (für 5 Volt) liegt.

`sensorWert = analogRead(sensorPin);`

#### delay(sensorWert);

Der Arduino ist sehr, sehr schnell – er kann tausende Zeilen Code pro Sekunde verarbeiten. Um ihn ein wenig auszubremsen, damit wir überhaupt sehen können, was er tut, fügen wir häufig kleine Pausen in den Code ein. `delay()` zählt in Millisekunden; eine Sekunde besteht aus 1000 Millisekunden.

### Was Du sehen solltest:

Du solltest die LED schneller oder langsamer blinken sehen, je nachdem, wie das Potentiometer eingestellt ist. Falls das nicht funktioniert: Prüfe, ob Du den Schaltkreis richtig aufgebaut und den Code richtig geprüft und hochgeladen hast – oder schau Dir die Fehlersuche-Tipps unten an.

### Fehlersuche:

#### Mal funktioniert's, mal nicht
Das liegt höchstwahrscheinlich an einem Wackelkontakt an einem der Potentiometer-Pins. Normalerweise reicht hier, das Potentiometer richtig auf das Steckbrett zu drücken und zu halten.

#### Gar nichts funktioniert
Stelle sicher, dass Du nicht aus Versehen den mittleren Pin des Potentiometers an den **digitalen** Pin 0 anstelle des analogen Pin A0 angeschlossen hast.

### Anwendung in der echten Welt:

Die meisten Lautstärkeregler verwenden ein Potentiometer.

## Schaltung 3: Eine RGB-LED

Was ist noch spannender, als eine LED zum Blinken zu bekommen? Verschiedene Farben mit nur einer LED. RGB-LEDs (Rot-Grün-Blau) haben drei Leuchtdioden unterschiedlicher Farben im selben Gehäuse, die zusammen alle möglichen Farben erzeugen können. In diesem Schaltkreis lernst Du, wie Du mit einer RGB-LED viele Farbkombinationen erzeugen kannst. Je nachdem, wie hell die einzelnen Farben jeweils leuchten, kannst du beinahe alle denkbaren Farben erzeugen!

Der Aufbau von Schaltkreis 3. Abbildung nach dem SIK, http://creativecommons.org/by-sa/3.0/

### Teile:

 * RGB-LED (1×)
 * 330Ω-Widerstand (3×)
 * Drahtbrücken (6×)

### Die ganze Wahrheit hinter analogWrite():

Wir haben schon gesehen, dass der Arduino analoge Spannungen (Spannungen zwischen 0 und 5 Volt) mit der analogRead()-Funktion einlesen kann. Gibt es auch eine Möglichkeit, mit dem uulmduino analoge Spannungen auszugeben?

Die Antwort ist nein… und ja. Der uulmduino hat keinen richtigen analogen Spannungsausgan. Aber weil er so schnell ist, kann er ein wenig schummeln, indem er sogenannte PWM benutzt („Pulsweitenmodulation“). Die Pins auf dem uulmduino, neben denen ein „~“ steht, können PWM/Analog-Ausgabe.

Der uulmduino ist so schnell, dass er einen Pin beinahe 1000 Mal pro Sekunde an- und ausschalten kann. PWM geht noch einen Schritt weiter, indem die jeweiligen Anteile der an- und ausgeschalteten Zeit gegeneinander verschoben werden. Wenn der Pin die meiste Zeit auf HIGH geschaltet ist, wirkt eine an den Pin angeschlossene LED sehr hell. Wenn der Pin die meiste Zeit auf LOW geschaltet ist, sieht die LED eher dunkel aus. Weil der Pin deutlich schneller blinkt als Dein Auge erkennen kann, erzeugt der uulmduino die Illusion eines „echten“ analogen Ausgangs.

### Codeschnipsel

> for (x = 0; x < 768; x++) 
> {}

Hier wird eine for()-Schleife benutzt, um einen bestimmten Zahlenbereich durchzuzählen, und jedes Mal wird dann der Code innerhalb der geschweiften Klammern ausgeführt. Hier fängt die Variable "x" bei 0 zu zählen an, hört bei 767 auf, und wird jedes Mal um eins weitergezählt ("x++")

> if (x <= 255)
> {}
> else
> {}

„If-Else“-Ausdrücke („Wenn…sonst“) werden benutzt, um in Deinem Code Entscheidungen zu treffen. Der Ausdruck innerhalb der runden Klammern () wird geprüft; falls er zutrifft (“true”, also „wahr“), wird der Code innerhalb der ersten geschweiften Klammern ausgeführt. Falls er nicht zutrifft, wird der Code innerhalb der zweiten geschweiften Klammern (nach dem “else”) ausgeführt.

> delay(sensorValue); 

Der uulmduino ist sehr sehr schnell – er kann tausende Codezeilen pro Sekunde ausführen. Um ihn ein wenig auszubremsen, damit wir überhaupt sehen können, was er tut, fügen wir häufig kleine Pausen in den Code ein. delay() zählt in Millisekunden; eine Sekunde besteht aus 1000 Millisekunden.
there are 1000 ms in one second.

### Was Du sehen solltest

Du solltest deine LED wieder leuchten sehen, aber dieses Mal in neuen, verrückten Farben! Falls sie das nicht tut, stelle sicher, dass Du den Schaltkreis richtig aufgebaut und den Code geprüft und hochgeladen hast – oder gehe die Tipps zur Fehlersuche weiter unten durch.

### Fehlersuche

#### LED bleibt dunkel oder zeigt falsche Farben
Da die vier Beinchen der LED so nah beisammen sind, kann es vorkommen, dass man sie falsch einsteckt. Prüfe nochmal genau, ob jeder Pin dort ist, wo er sein sollte.

#### Du siehst Rot
Die rote Diode in der RGB-LED kann etwas heller sein als die anderen beiden. Um die Farben etwas ausgeglichener zu machen, kannst du einen höherohmigen Widerstand an ihren Pin anschließen. Oder passe den Code an: aus analogWrite(RED_PIN, redIntensity); wird analogWrite(RED_PIN, redIntensity/3);

### Anwendung in der echten Welt

Viele elektronischen Geräte wie zum Beispiel Spielkonsolen benutzen RGB-LEDs, um an derselben Stelle gleich mehrere Farben anzeigen zu können. Häufig stehen die verschiedenen Farben für verschiedene Betriebs- oder Fehlerzustände.

# Optionale Dinge für Zuhause

Je nachdem, was Du zuhause mit deinem uulmduino anstellen magst, gibt es noch verschiedene Optionen, die Du zu jeder Zeit umstellen kannst.

## Steckbrücken einstellen

 * USB-VIN: Wenn Du hier eine Drahtbrücke oder einen Steckplatz für einen Jumper einlötest, kannst Du die 5V-Leitung deines USB-Adapters verwenden, um den uulmduino anzutreiben. Löte diese Verbindung ein, wenn Du die Platine über USB mit Strom versorgen möchtest. Wenn Du diese Option wählst, stelle sicher, dass Du alle anderen Stromquellen trennst, bevor Du das USB-TTL-Kabel einsteckst – Du kannst immer nur eine Stromquelle auf einmal benutzen.
 * Drahtbrücke für den Spannungsregler (REG BYPASS): Diese Brücke verbindet den Gleichstromeingang („DC in“) direkt mit der Versorgungsspannung. Löte sie nur ein, wenn Du ein Netzteil mit genau 5V verwendest, also keinen Spannungsregler brauchst. Wenn du einen Spannungsregler einlötest, lass diese Brücke frei.
 
## Wichtige Tipps

 * Der AVR-Microcontroller benötigt 4,5–5,5V (Vcc), wenn er mit 16 MHz läuft.
 * Achte darauf, die Platine immer nur mit **einer** Spannungsquelle zu versorgen: USB-TTL, externes Netzteil oder Batteriespannung.
 * Für die Programmierung brauchst Du ein FTDI-TTL-232R-Kabel oder einen vergleichbaren USB-TTL-Adapter.
 * In der Arduino-IDE wählst Du zur Programmierung (im Menü) „Duemilanove w/'328“ als Modell aus.

## Ein 5V-Netzteil benutzen

Wenn Du auf die Stelle **DC IN** eine Hohlbuchse lötest, kannst Du ein geregeltes 5V-Gleichspannungsnetzteil (Pluspol außenliegend) verwenden, um den uulmduino anzutreiben. Da es Dir schon direkt 5V bereitstellt, brauchst (und kannst) du keinen zusätzlichen Spannungsregler auf der Platine verwenden.

Um diese Art von Netzteil zu verwenden, löte einfach die DC-Anschlussbuchse ein – und eine Drahtbrücke zwischen den beiden Anschlüssen von **REG BYPASS** 

## Ein Netzteil mit mehr als 6V benutzen

Du kannst aber auch ein 9V-Gleichspannungsnetzteil (Pluspol außenliegend) verwenden. Da es mehr als 5V bereitstellt, brauchst du einen 5V-Spannungsregler, um es zu verwenden.

Neben der Anschlussbuchse musst Du auch den 5V-Spannungsregler einlöten. Löte hier **nicht** die Spannungsregler-Brücke (REG BYPASS) ein – das würde den Regler kurzschließen.

Zum Spannungsregler gehören drei Teile: Ein 0,1µF-Keramikkondensator (C4), der Regler selbst (TL750L05), und ein 10µF-Elektrolytkondesator („Elko“, C5).

Unser normaler Regler ist vom Typ 750L05 und stellt 150 mA bereit. Du kannst auch den Typ L4931CZ50-AP verwenden, der 300 mA schafft.

*Die Ausrichtung des Reglers ist wichtig:* Die flache Seite des Reglers muss mit der flachen Seite der Zeichnung auf der Platine übereinstimmen.

*Die Ausrichtung des Elko ist wichtig:* Die Seite mit dem großen **–**-Streifen muss zum **–** auf der Platine zeigen.

*Anmerkung:* Auch hier gilt, trenne bzw. schalte alle anderen Spannungsquellen ab, bevor Du Dein Netzteil einsteckst. Du kannst nur **eine** Spannungsquelle gleichzeitig verwenden.

## Weitere Experimente

Die Experimente in diesem Handbuch sind aus dem Sparkfun Inventors' Kit, das Du auf https://www.sparkfun.com/products/12060 findest. Das SIK-Handbuch und die Codebeispiele sind auf Englisch – wir arbeiten aber daran, Sparkfun unsere Übersetzung wieder zurückzugeben.

# Zum Schluss

Wir hoffen, Du hattest Spaß bei unserem Girls'Day. Das war das erste Mal, dass wir so etwas umfangreiches selber entwickelt haben – es würde uns freuen, wenn Du uns Feedback gibst, was wir gut gemacht haben, und was wir noch besser machen sollten.

Du erreichst uns unter in.wissenschaffer@uni-ulm.de!

Dein WissenSchaffer-Team  
Anna, Jens, Juliane, Maria, Philipp, Stefan und die Tobiase ;)

## Rechtliches

Dieses Handbuch ist eine Open Educational Resource und unterliegt der CC-BY-SA-Lizenz. Der Text der Lizenz ist unter http://creativecommons.org/by-sa/3.0/ einsehbar. Die Abbildungen zum Breadboard und den Schaltkreisen sind aus dem SIK-Handbuch von Sparkfun und unterliegen ebenfalls der CC-BY-SA-Lizenz.  
Die Quelldateien sowie die EDA-Vorlagen für die Platine landen hoffentlich bald auf http://github.com/stkdiretto/uulmduino ;)

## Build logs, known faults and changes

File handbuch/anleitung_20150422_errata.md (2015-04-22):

# uulmduino – Errata zur Anleitung

Nicht immer klappt alles gleich beim ersten Mal, und so hat sich auch in die erste Version des uulmduino ein kleiner Fehler eingeschlichen. Der Jumper für die TV-B-Gone ist mit Pin 9 verbunden – stattdessen muss Pin 10 verbunden werden. Das geht wahlweise mit einem Stückchen isolierten Drahts, das zwischen der Unterseite von Pin 10 und dem (von oben) **linken** Anschluss des TV-B-Gone-Jumpers verbunden wird, oder mit einer Steckbrücke zwischen der Oberseite von Pin 10 und dem (von oben) **linken** Anschluss des TV-B-Gone-Jumpers.

Die linke Seite des TV-B-Gone-Jumpers ist die, von der auf der Oberseite sichtbar eine Leitung zum Widerstand R5 geht – also in Richtung des USB-TTL-Anschluss :)

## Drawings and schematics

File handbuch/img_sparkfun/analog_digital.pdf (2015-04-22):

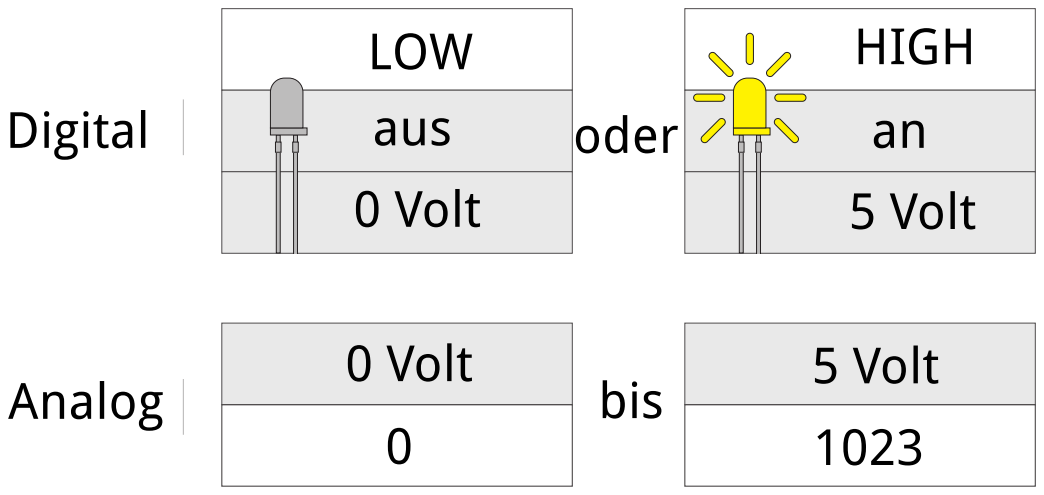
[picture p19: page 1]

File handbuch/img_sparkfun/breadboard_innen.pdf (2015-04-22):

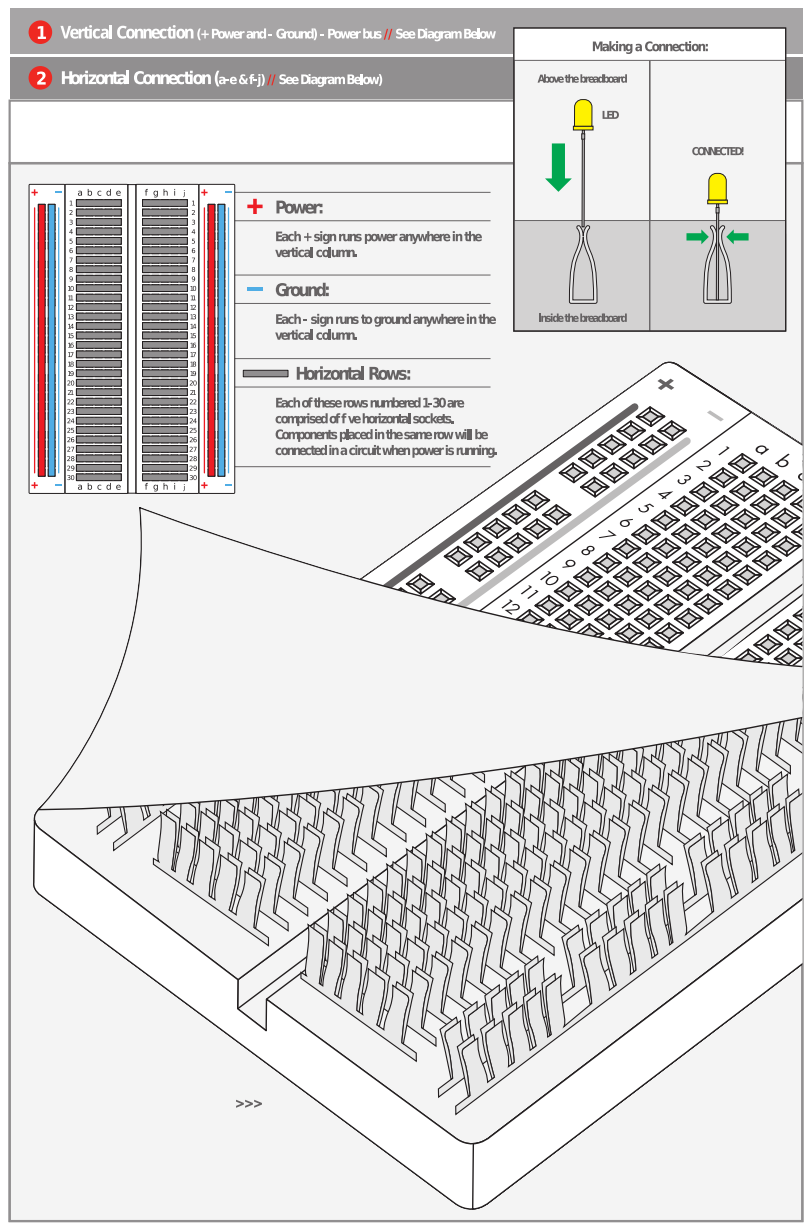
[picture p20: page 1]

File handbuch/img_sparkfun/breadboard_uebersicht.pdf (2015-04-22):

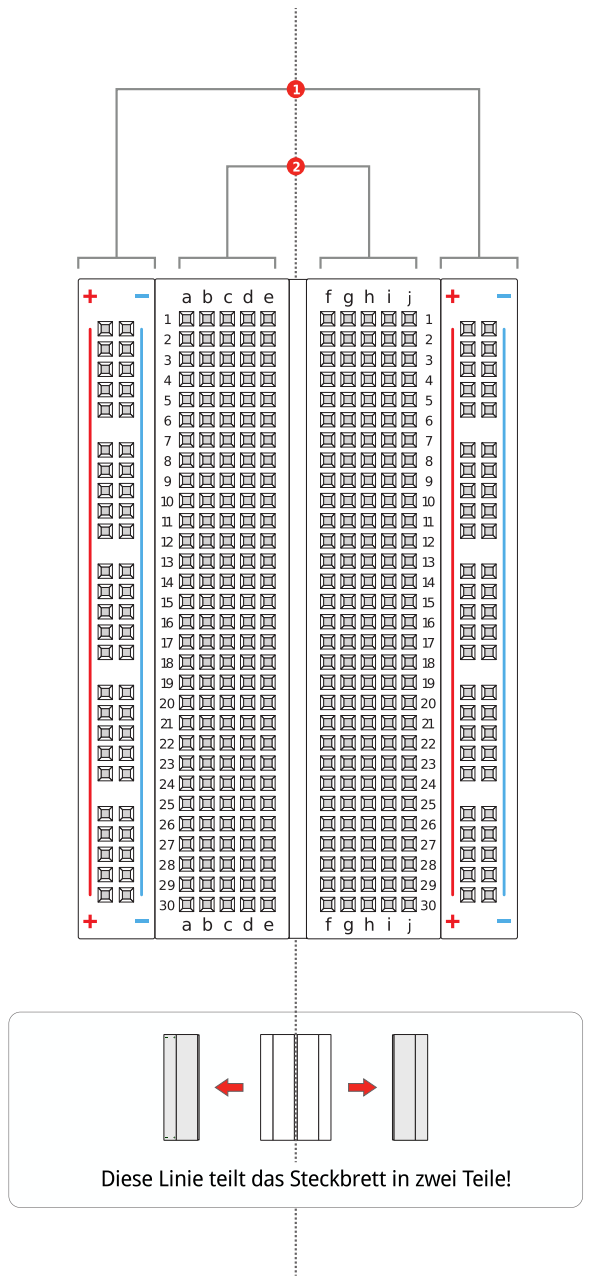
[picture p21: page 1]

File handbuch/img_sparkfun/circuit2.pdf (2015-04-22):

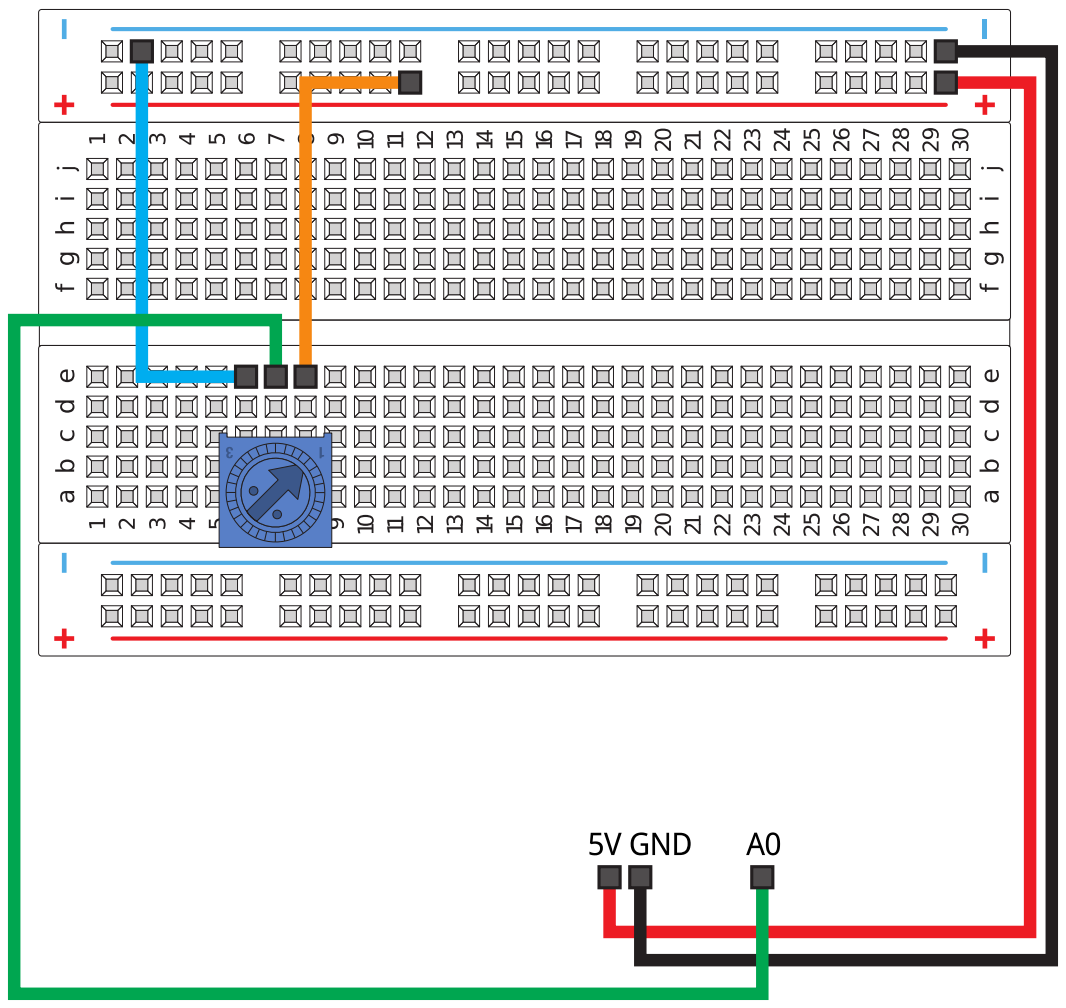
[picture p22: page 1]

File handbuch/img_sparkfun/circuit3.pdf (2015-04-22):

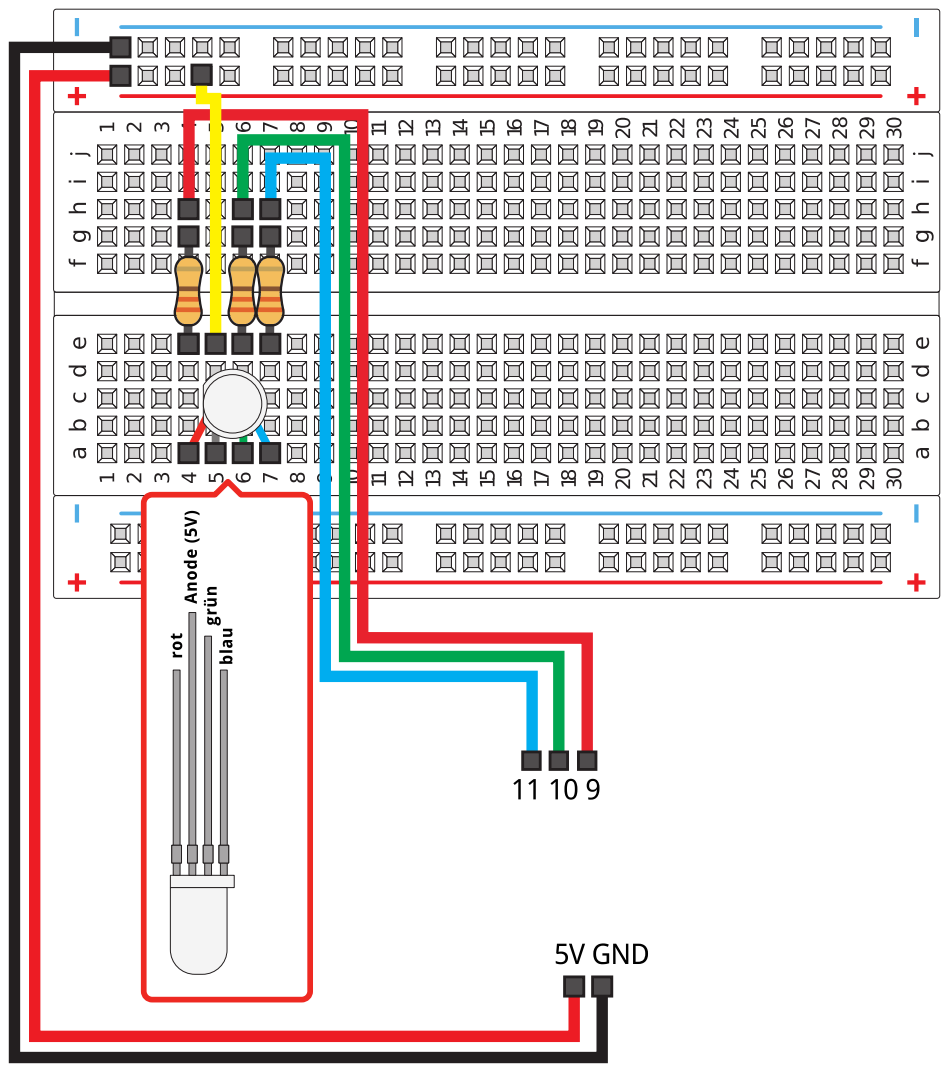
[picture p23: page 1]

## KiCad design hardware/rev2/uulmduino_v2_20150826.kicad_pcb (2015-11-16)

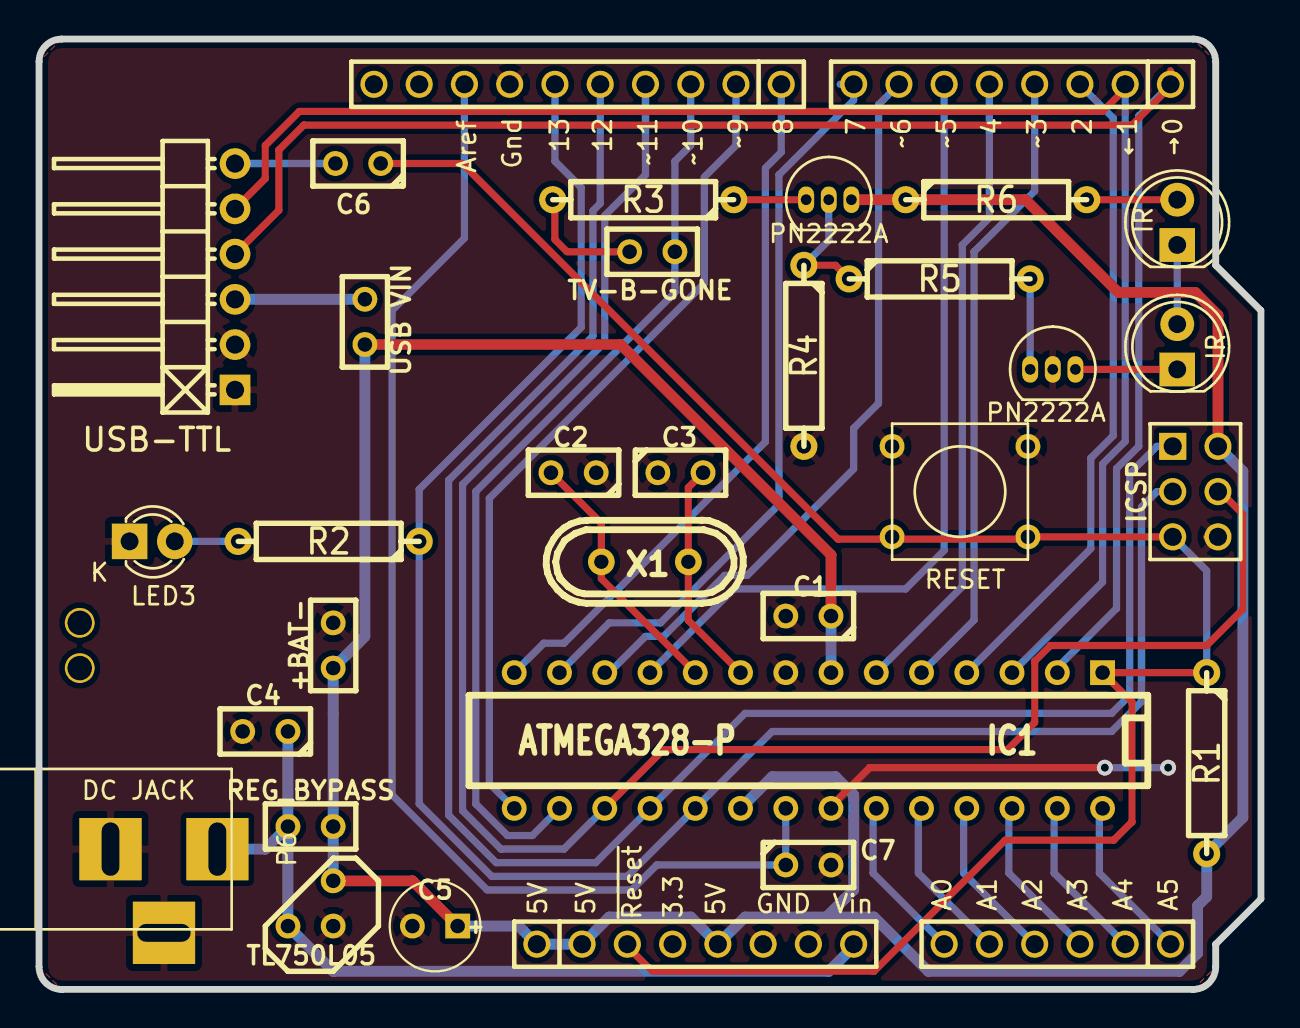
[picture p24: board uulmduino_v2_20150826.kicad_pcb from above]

Board: 2 copper layers, 68.6 x 53.3 mm, 35 parts (0 on the bottom side), 37 nets.

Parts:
1PIN, 1PIN#2: P***; 1pin_mechanical
+BAT-: BATTERY IN; SIL-2
C1, C4, C6, C7: 0.1µF; C1
C2, C3: 18pF; C1
C5: 10µF; C1V5
IC1: ATMEGA328-P; DIP-28__300
ICSP: CONN_3X2; pin_array_3x2
LED1, LED2: IR; LED-5MM
LED3: PIN13; LED-3MM
P1: CONN_10; HEADER_100MIL_1R10P_PTH
P2, P4: CONN_8; HEADER_100MIL_1R8P_PTH
P3: CONN_6; HEADER_100MIL_1R6P_PTH
P6: DC JACK; BARREL_JACK
Q1, Q2: PN2222A; TO-92_Inline_Narrow_Oval
R1, R4: 10k; R4
R2: 1k; R4
R3: R; R4
R5: 100; R4
R6: 220; R4
REG_BYPASS: Regulator bypass; SIL-2
SW1: RESET; SW_PUSH_SMALL
TV-B-GONE: TV_B_GONE; SIL-2
U1: TL750L05; LM78XX-TO92
USB VIN: VCC USB; SIL-2
USB-TTL: CONN_6; Pin_Header_Angled_1x06
X1: 16 MHz; Crystal_HC49-U_Vertical

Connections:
5V: +BAT-.1, C1.1, C5.1, IC1.7, IC1.20, ICSP.2, P4.1, P4.2, P4.5, Q1.3, R1.2, R6.1, REG_BYPASS.2, U1.VO, USB VIN.2
AD0: IC1.23, P3.6
AD1: IC1.24, P3.5
AD2: IC1.25, P3.4
AD3: IC1.26, P3.3
AD4/SDA: IC1.27, P3.2
AD5/SCL: IC1.28, P3.1
AREF: C7.1, IC1.21, P1.8
GND: +BAT-.2, C1.2, C2.1, C3.1, C4.2, C5.2, C7.2, IC1.8, IC1.22, ICSP.6, LED3.1, P1.7, P4.6, P4.7, P6.2, P6.3, Q2.2, R4.2, SW1.1, U1.GND, USB-TTL.1, USB-TTL.2
IO0: IC1.2, P2.1, USB-TTL.4
IO1: IC1.3, P2.2, USB-TTL.5
IO2: IC1.4, P2.3
IO3: IC1.5, P2.4
IO4: IC1.6, P2.5
IO5: IC1.11, P2.6
IO6: IC1.12, P2.7
IO7: IC1.13, P2.8
IO8: IC1.14, P1.1
IO9: IC1.15, P1.2
IO10/SS: IC1.16, P1.3, TV-B-GONE.1
IO11/MOSI: IC1.17, ICSP.4, P1.4
IO12/MISO: IC1.18, ICSP.1, P1.5
IO13/SCK: IC1.19, ICSP.3, P1.6, R2.1
unnamed: C2.2, IC1.10, X1.2
unnamed: C3.2, IC1.9, X1.1
unnamed: C6.2, USB-TTL.6
unnamed: USB VIN.1, USB-TTL.3
unnamed: R3.2, TV-B-GONE.2
unnamed: LED1.1, LED2.2
unnamed: LED1.2, R6.2
unnamed: LED2.1, Q2.3
unnamed: LED3.2, R2.2
unnamed: Q1.1, R3.1
unnamed: Q1.2, R4.1, R5.1
unnamed: Q2.1, R5.2
RESET: C6.1, IC1.1, ICSP.5, P4.3, R1.1, SW1.2
VIN: C4.1, P4.8, P6.1, REG_BYPASS.1, U1.VI

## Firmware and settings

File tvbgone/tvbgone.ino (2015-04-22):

/*
TV-B-Gone für den uulmduino, Version 1.2ulm, 22. April 2015

Basierend auf TV-B-Gone for Arduino version 1.2, Oct 23 2010
von Ken Shirriff=
http://www.arcfn.com/2009/12/tv-b-gone-for-arduino.html

Dies ist auf die Arduino-IDE >1.0.5 und den uulmduino v.0.1 zugeschnitten
Abweichend von Ken Shirriffs Version wird Timer1 benutzt, um auf dem
Platinenlayout nicht Pin3 nutzen zu müssen.
 Der IR-Ausgang wird an Pin 10 angelegt (IRLED).
 Die eingebaute LED auf Pin 13 wird ebenfalls verwendet.
 Theoretisch kann ein Button als Trigger zwischen Pin 2 (TRIGGER) und Masse
    verwendet werden.
 Pin 5 (REGIONSWITCH) wird nicht benutzt.

The original code is:
TV-B-Gone Firmware version 1.2
 for use with ATtiny85v and v1.2 hardware
 (c) Mitch Altman + Limor Fried 2009
 Last edits, August 16 2009


 I added universality for EU or NA,
 and Sleep mode to Ken's Arduino port
      -- Mitch Altman  18-Oct-2010
 Thanks to ka1kjz for the code for adding Sleep
      <http://www.ka1kjz.com/561/adding-sleep-to-tv-b-gone-code/>


 With some code from:
 Kevin Timmerman & Damien Good 7-Dec-07

 Distributed under Creative Commons 2.5 -- Attib & Share Alike

 */

#include "main.h"
#include <avr/sleep.h>

void xmitCodeElement(uint16_t ontime, uint16_t offtime, uint8_t PWM_code );
void quickflashLEDx( uint8_t x );
void delay_ten_us(uint16_t us);
void quickflashLED( void );
uint8_t read_bits(uint8_t count);

#define putstring_nl(s) Serial.println(s)
#define putstring(s) Serial.print(s)
#define putnum_ud(n) Serial.print(n, DEC)
#define putnum_uh(n) Serial.print(n, HEX)

/*
Dieses Projekt überträgt eine Reihe von TV-Ausschaltcodes, einen nach dem
 anderen, mit einer kurzen Pause zwischen jedem Code. Um direkt zu sehen,
 dass übertragen wird, blinkt auch die LED auf Pin13 bei jedem Code. Das ist
 alles, was TV-B-Gone tut. Der schwierige Teil war, alle Ausschaltcodes zu
 sammeln, und die Dubletten auszusortieren (wenn ein Code doppelt vorkommt,
 wird ein Fernseher erst aus- und dann bei der zweiten Übertragung wieder
 angeschaltet). Die Originale von Mitch Altman und Ken Shirriff haben die 
 üblichen Codes für Nordamerika (und auch Asien, obwohl dort vielfach PAL
 für die Übertragung verwendet wird) und Europa (passend auch in Australien,
 Neuseeland, im nahen Osten und anderen Teilen der Welt, wo PAL benutzt 
 wird) gesammelt.

 Diese Firmwareversion beinhaltet die jeweils über 100 meistgenutzten 
 Ausschaltcodes für Europa und Nordamerika.
 */


/*
This project is a good example of how to use the AVR chip timers.
 */

//Codes captured from Generation 3 TV-B-Gone by Limor Fried & Mitch Altman
// table of POWER codes

const uint16_t code_na000Times[] PROGMEM = {
  60, 60,
  60, 2700,
  120, 60,
  240, 60,
};
const uint8_t code_na000Codes[] PROGMEM = {
  0xE2,
  0x20,
  0x80,
  0x78,
  0x88,
  0x20,
  0x10,
};
const struct IrCode code_na000Code PROGMEM = {
  freq_to_timerval(38400),
  26,             // # of pairs
  2,              // # of bits per index
  code_na000Times,
  code_na000Codes
};

const uint16_t code_na001Times[] PROGMEM = {
  50, 100,
  50, 200,
  50, 800,
  400, 400,
};
const uint8_t code_na001Codes[] PROGMEM = {
  0xD5,
  0x41,
  0x11,
  0x00,
  0x14,
  0x44,
  0x6D,
  0x54,
  0x11,
  0x10,
  0x01,
  0x44,
  0x45,
};
const struct IrCode code_na001Code PROGMEM = {
  freq_to_timerval(57143),
  52,		// # of pairs
  2,		// # of bits per index
  code_na001Times,
  code_na001Codes
};
const uint16_t code_na002Times[] PROGMEM = {
  42, 46,
  42, 133,
  42, 7519,
  347, 176,
  347, 177,
};
const uint8_t code_na002Codes[] PROGMEM = {
  0x60,
  0x80,
  0x00,
  0x00,
  0x00,
  0x08,
  0x00,
  0x00,
  0x00,
  0x20,
  0x00,
  0x00,
  0x04,
  0x12,
  0x48,
  0x04,
  0x12,
  0x48,
  0x2A,
  0x02,
  0x00,
  0x00,
  0x00,
  0x00,
  0x20,
  0x00,
  0x00,
  0x00,
  0x80,
  0x00,
  0x00,
  0x10,
  0x49,
  0x20,
  0x10,
  0x49,
  0x20,
  0x80,
};
const struct IrCode code_na002Code PROGMEM = {
  freq_to_timerval(37037),
  100,		// # of pairs
  3,		// # of bits per index
  code_na002Times,
  code_na002Codes
};
const uint16_t code_na003Times[] PROGMEM = {
  26, 185,
  27, 80,
  27, 185,
  27, 4549,
};
const uint8_t code_na003Codes[] PROGMEM = {
  0x15,
  0x5A,
  0x65,
  0x67,
  0x95,
  0x65,
  0x9A,
  0x9B,
  0x95,
  0x5A,
  0x65,
  0x67,
  0x95,
  0x65,
  0x9A,
  0x99,
};
const struct IrCode code_na003Code PROGMEM = {
  freq_to_timerval(38610),
  64,		// # of pairs
  2,		// # of bits per index
  code_na003Times,
  code_na003Codes
};
const uint16_t code_na004Times[] PROGMEM = {
  55, 57,
  55, 170,
  55, 3949,
  55, 9623,
  56, 0,
  898, 453,
  900, 226,
};
const uint8_t code_na004Codes[] PROGMEM = {
  0xA0,
  0x00,
  0x01,
  0x04,
  0x92,
  0x48,
  0x20,
  0x80,
  0x40,
  0x04,
  0x12,
  0x09,
  0x2B,
  0x3D,
  0x00,
};
const struct IrCode code_na004Code PROGMEM = {
  freq_to_timerval(38610),
  38,		// # of pairs
  3,		// # of bits per index
  code_na004Times,
  code_na004Codes
};
const uint16_t code_na005Times[] PROGMEM = {
  88, 90,
  88, 91,
  88, 181,
  88, 8976,
  177, 91,
};
const uint8_t code_na005Codes[] PROGMEM = {
  0x10,
  0x92,
  0x49,
  0x46,
  0x33,
  0x09,
  0x24,
  0x94,
  0x60,
};
const struct IrCode code_na005Code PROGMEM = {
  freq_to_timerval(35714),
  24,		// # of pairs
  3,		// # of bits per index
  code_na005Times,
  code_na005Codes
};
const uint16_t code_na006Times[] PROGMEM = {
  50, 62,
  50, 172,
  50, 4541,
  448, 466,
  450, 465,
};
const uint8_t code_na006Codes[] PROGMEM = {
  0x64,
  0x90,
  0x00,
  0x04,
  0x90,
  0x00,
  0x00,
  0x80,
  0x00,
  0x04,
  0x12,
  0x49,
  0x2A,
  0x12,
  0x40,
  0x00,
  0x12,
  0x40,
  0x00,
  0x02,
  0x00,
  0x00,
  0x10,
  0x49,
  0x24,
  0x90,
};
const struct IrCode code_na006Code PROGMEM = {
  freq_to_timerval(38462),
  68,		// # of pairs
  3,		// # of bits per index
  code_na006Times,
  code_na006Codes
};
const uint16_t code_na007Times[] PROGMEM = {
  49, 49,
  49, 50,
  49, 410,
  49, 510,
  49, 12107,
};
const uint8_t code_na007Codes[] PROGMEM = {
  0x09,
  0x94,
  0x53,
  0x29,
  0x94,
  0xD9,
  0x85,
  0x32,
  0x8A,
  0x65,
  0x32,
  0x9B,
  0x20,
};
const struct IrCode code_na007Code PROGMEM = {
  freq_to_timerval(39216),
  34,		// # of pairs
  3,		// # of bits per index
  code_na007Times,
  code_na007Codes
};
const uint16_t code_na008Times[] PROGMEM = {
  56, 58,
  56, 170,
  56, 4011,
  898, 450,
  900, 449,
};
const uint8_t code_na008Codes[] PROGMEM = {
  0x64,
  0x00,
  0x49,
  0x00,
  0x92,
  0x00,
  0x20,
  0x82,
  0x01,
  0x04,
  0x10,
  0x48,
  0x2A,
  0x10,
  0x01,
  0x24,
  0x02,
  0x48,
  0x00,
  0x82,
  0x08,
  0x04,
  0x10,
  0x41,
  0x20,
  0x90,
};
const struct IrCode code_na008Code PROGMEM = {
  freq_to_timerval(38462),
  68,		// # of pairs
  3,		// # of bits per index
  code_na008Times,
  code_na008Codes
};
const uint16_t code_na009Times[] PROGMEM = {
  53, 56,
  53, 171,
  53, 3950,
  53, 9599,
  898, 451,
  900, 226,
};
const uint8_t code_na009Codes[] PROGMEM = {
  0x84,
  0x90,
  0x00,
  0x20,
  0x80,
  0x08,
  0x00,
  0x00,
  0x09,
  0x24,
  0x92,
  0x40,
  0x0A,
  0xBA,
  0x40,
};
const struct IrCode code_na009Code PROGMEM = {
  freq_to_timerval(38462),
  38,		// # of pairs
  3,		// # of bits per index
  code_na009Times,
  code_na009Codes
};
const uint16_t code_na010Times[] PROGMEM = {
  51, 55,
  51, 158,
  51, 2286,
  841, 419,
};
const uint8_t code_na010Codes[] PROGMEM = {
  0xD4,
  0x00,
  0x15,
  0x10,
  0x25,
  0x00,
  0x05,
  0x44,
  0x09,
  0x40,
  0x01,
  0x51,
  0x01,
};
const struct IrCode code_na010Code PROGMEM = {
  freq_to_timerval(38462),
  52,		// # of pairs
  2,		// # of bits per index
  code_na010Times,
  code_na010Codes
};
const uint16_t code_na011Times[] PROGMEM = {
  55, 55,
  55, 172,
  55, 4039,
  55, 9348,
  56, 0,
  884, 442,
  885, 225,
};
const uint8_t code_na011Codes[] PROGMEM = {
  0xA0,
  0x00,
  0x41,
  0x04,
  0x92,
  0x08,
  0x24,
  0x90,
  0x40,
  0x00,
  0x02,
  0x09,
  0x2B,
  0x3D,
  0x00,
};
const struct IrCode code_na011Code PROGMEM = {
  freq_to_timerval(38462),
  38,		// # of pairs
  3,		// # of bits per index
  code_na011Times,
  code_na011Codes
};
const uint16_t code_na012Times[] PROGMEM = {
  81, 87,
  81, 254,
  81, 3280,
  331, 336,
  331, 337,
};
const uint8_t code_na012Codes[] PROGMEM = {
  0x64,
  0x12,
  0x08,
  0x24,
  0x00,
  0x08,
  0x20,
  0x10,
  0x09,
  0x2A,
  0x10,
  0x48,
  0x20,
  0x90,
  0x00,
  0x20,
  0x80,
  0x40,
  0x24,
  0x90,
};
const struct IrCode code_na012Code PROGMEM = {
  freq_to_timerval(38462),
  52,		// # of pairs
  3,		// # of bits per index
  code_na012Times,
  code_na012Codes
};
const uint16_t code_na013Times[] PROGMEM = {
  53, 55,
  53, 167,
  53, 2304,
  53, 9369,
  893, 448,
  895, 447,
};
const uint8_t code_na013Codes[] PROGMEM = {
  0x80,
  0x12,
  0x40,
  0x04,
  0x00,
  0x09,
  0x00,
  0x12,
  0x41,
  0x24,
  0x82,
  0x01,
  0x00,
  0x10,
  0x48,
  0x24,
  0xAA,
  0xE8,
};
const struct IrCode code_na013Code PROGMEM = {
  freq_to_timerval(38462),
  48,		// # of pairs
  3,		// # of bits per index
  code_na013Times,
  code_na013Codes
};

/* Duplicate timing table, same as na004 !
 const uint16_t code_na014Times[] PROGMEM = {
 	55, 57,
 	55, 170,
 	55, 3949,
 	55, 9623,
 	56, 0,
 	898, 453,
 	900, 226,
 };
 */
const uint8_t code_na014Codes[] PROGMEM = {
  0xA0,
  0x00,
  0x09,
  0x04,
  0x92,
  0x40,
  0x24,
  0x80,
  0x00,
  0x00,
  0x12,
  0x49,
  0x2B,
  0x3D,
  0x00,
};
const struct IrCode code_na014Code PROGMEM = {
  freq_to_timerval(38462),
  38,		// # of pairs
  3,		// # of bits per index
  code_na004Times,
  code_na014Codes
};

/* Duplicate timing table, same as na004 !
 const uint16_t code_na015Times[] PROGMEM = {
 	55, 57,
 	55, 170,
 	55, 3949,
 	55, 9623,
 	56, 0,
 	898, 453,
 	900, 226,
 };
 */
const uint8_t code_na015Codes[] PROGMEM = {
  0xA0,
  0x80,
  0x01,
  0x04,
  0x12,
  0x48,
  0x24,
  0x00,
  0x00,
  0x00,
  0x92,
  0x49,
  0x2B,
  0x3D,
  0x00,
};
const struct IrCode code_na015Code PROGMEM = {
  freq_to_timerval(38462),
  38,		// # of pairs
  3,		// # of bits per index
  code_na004Times,
  code_na015Codes
};
const uint16_t code_na016Times[] PROGMEM = {
  28, 90,
  28, 211,
  28, 2507,
};
const uint8_t code_na016Codes[] PROGMEM = {
  0x54,
  0x04,
  0x10,
  0x00,
  0x95,
  0x01,
  0x04,
  0x00,
  0x10,
};
const struct IrCode code_na016Code PROGMEM = {
  freq_to_timerval(34483),
  34,		// # of pairs
  2,		// # of bits per index
  code_na016Times,
  code_na016Codes
};
const uint16_t code_na017Times[] PROGMEM = {
  56, 57,
  56, 175,
  56, 4150,
  56, 9499,
  898, 227,
  898, 449,
};
const uint8_t code_na017Codes[] PROGMEM = {
  0xA0,
  0x02,
  0x48,
  0x04,
  0x90,
  0x01,
  0x20,
  0x80,
  0x40,
  0x04,
  0x12,
  0x09,
  0x2A,
  0x38,
  0x00,
};
const struct IrCode code_na017Code PROGMEM = {
  freq_to_timerval(40000),
  38,		// # of pairs
  3,		// # of bits per index
  code_na017Times,
  code_na017Codes
};
const uint16_t code_na018Times[] PROGMEM = {
  51, 55,
  51, 161,
  51, 2566,
  849, 429,
  849, 430,
};
const uint8_t code_na018Codes[] PROGMEM = {
  0x60,
  0x82,
  0x08,
  0x24,
  0x10,
  0x41,
  0x00,
  0x12,
  0x40,
  0x04,
  0x80,
  0x09,
  0x2A,
  0x02,
  0x08,
  0x20,
  0x90,
  0x41,
  0x04,
  0x00,
  0x49,
  0x00,
  0x12,
  0x00,
  0x24,
  0xA8,
  0x08,
  0x20,
  0x82,
  0x41,
  0x04,
  0x10,
  0x01,
  0x24,
  0x00,
  0x48,
  0x00,
  0x92,
  0xA0,
  0x20,
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
};
const struct IrCode code_na018Code PROGMEM = {
  freq_to_timerval(38462),
  136,		// # of pairs
  3,		// # of bits per index
  code_na018Times,
  code_na018Codes
};
const uint16_t code_na019Times[] PROGMEM = {
  40, 42,
  40, 124,
  40, 4601,
  325, 163,
  326, 163,
};
const uint8_t code_na019Codes[] PROGMEM = {
  0x60,
  0x10,
  0x40,
  0x04,
  0x80,
  0x09,
  0x00,
  0x00,
  0x00,
  0x00,
  0x10,
  0x00,
  0x20,
  0x10,
  0x00,
  0x20,
  0x80,
  0x00,
  0x0A,
  0x00,
  0x41,
  0x00,
  0x12,
  0x00,
  0x24,
  0x00,
  0x00,
  0x00,
  0x00,
  0x40,
  0x00,
  0x80,
  0x40,
  0x00,
  0x82,
  0x00,
  0x00,
  0x00,
};
const struct IrCode code_na019Code PROGMEM = {
  freq_to_timerval(38462),
  100,		// # of pairs
  3,		// # of bits per index
  code_na019Times,
  code_na019Codes
};
const uint16_t code_na020Times[] PROGMEM = {
  60, 55,
  60, 163,
  60, 4099,
  60, 9698,
  61, 0,
  898, 461,
  900, 230,
};
const uint8_t code_na020Codes[] PROGMEM = {
  0xA0,
  0x10,
  0x00,
  0x04,
  0x82,
  0x49,
  0x20,
  0x02,
  0x00,
  0x04,
  0x90,
  0x49,
  0x2B,
  0x3D,
  0x00,
};
const struct IrCode code_na020Code PROGMEM = {
  freq_to_timerval(38462),
  38,		// # of pairs
  3,		// # of bits per index
  code_na020Times,
  code_na020Codes
};
const uint16_t code_na021Times[] PROGMEM = {
  48, 52,
  48, 160,
  48, 400,
  48, 2335,
  799, 400,
};
const uint8_t code_na021Codes[] PROGMEM = {
  0x80,
  0x10,
  0x40,
  0x08,
  0x82,
  0x08,
  0x01,
  0xC0,
  0x08,
  0x20,
  0x04,
  0x41,
  0x04,
  0x00,
  0x00,
};
const struct IrCode code_na021Code PROGMEM = {
  freq_to_timerval(38462),
  38,		// # of pairs
  3,		// # of bits per index
  code_na021Times,
  code_na021Codes
};
const uint16_t code_na022Times[] PROGMEM = {
  53, 60,
  53, 175,
  53, 4463,
  53, 9453,
  892, 450,
  895, 225,
};
const uint8_t code_na022Codes[] PROGMEM = {
  0x80,
  0x02,
  0x40,
  0x00,
  0x02,
  0x40,
  0x00,
  0x00,
  0x01,
  0x24,
  0x92,
  0x48,
  0x0A,
  0xBA,
  0x00,
};
const struct IrCode code_na022Code PROGMEM = {
  freq_to_timerval(38462),
  38,		// # of pairs
  3,		// # of bits per index
  code_na022Times,
  code_na022Codes
};
const uint16_t code_na023Times[] PROGMEM = {
  48, 52,
  48, 409,
  48, 504,
  48, 10461,
};
const uint8_t code_na023Codes[] PROGMEM = {
  0xA1,
  0x18,
  0x61,
  0xA1,
  0x18,
  0x7A,
  0x11,
  0x86,
  0x1A,
  0x11,
  0x86,
};
const struct IrCode code_na023Code PROGMEM = {
  freq_to_timerval(40000),
  44,		// # of pairs
  2,		// # of bits per index
  code_na023Times,
  code_na023Codes
};
const uint16_t code_na024Times[] PROGMEM = {
  58, 60,
  58, 2569,
  118, 60,
  237, 60,
  238, 60,
};
const uint8_t code_na024Codes[] PROGMEM = {
  0x69,
  0x24,
  0x10,
  0x40,
  0x03,
  0x12,
  0x48,
  0x20,
  0x80,
  0x00,
};
const struct IrCode code_na024Code PROGMEM = {
  freq_to_timerval(38462),
  26,		// # of pairs
  3,		// # of bits per index
  code_na024Times,
  code_na024Codes
};
const uint16_t code_na025Times[] PROGMEM = {
  84, 90,
  84, 264,
  84, 3470,
  346, 350,
  347, 350,
};
const uint8_t code_na025Codes[] PROGMEM = {
  0x64,
  0x92,
  0x49,
  0x00,
  0x00,
  0x00,
  0x00,
  0x02,
  0x49,
  0x2A,
  0x12,
  0x49,
  0x24,
  0x00,
  0x00,
  0x00,
  0x00,
  0x09,
  0x24,
  0x90,
};
const struct IrCode code_na025Code PROGMEM = {
  freq_to_timerval(38462),
  52,		// # of pairs
  3,		// # of bits per index
  code_na025Times,
  code_na025Codes
};
const uint16_t code_na026Times[] PROGMEM = {
  49, 49,
  49, 50,
  49, 410,
  49, 510,
  49, 12582,
};
const uint8_t code_na026Codes[] PROGMEM = {
  0x09,
  0x94,
  0x53,
  0x65,
  0x32,
  0x99,
  0x85,
  0x32,
  0x8A,
  0x6C,
  0xA6,
  0x53,
  0x20,
};
const struct IrCode code_na026Code PROGMEM = {
  freq_to_timerval(39216),
  34,		// # of pairs
  3,		// # of bits per index
  code_na026Times,
  code_na026Codes
};

/* Duplicate timing table, same as na001 !
 const uint16_t code_na027Times[] PROGMEM = {
 	50, 100,
 	50, 200,
 	50, 800,
 	400, 400,
 };
 */
const uint8_t code_na027Codes[] PROGMEM = {
  0xC5,
  0x41,
  0x11,
  0x10,
  0x14,
  0x44,
  0x6C,
  0x54,
  0x11,
  0x11,
  0x01,
  0x44,
  0x44,
};
const struct IrCode code_na027Code PROGMEM = {
  freq_to_timerval(57143),
  52,		// # of pairs
  2,		// # of bits per index
  code_na001Times,
  code_na027Codes
};
const uint16_t code_na028Times[] PROGMEM = {
  118, 121,
  118, 271,
  118, 4750,
  258, 271,
};
const uint8_t code_na028Codes[] PROGMEM = {
  0xC4,
  0x45,
  0x14,
  0x04,
  0x6C,
  0x44,
  0x51,
  0x40,
  0x44,
};
const struct IrCode code_na028Code PROGMEM = {
  freq_to_timerval(38610),
  36,		// # of pairs
  2,		// # of bits per index
  code_na028Times,
  code_na028Codes
};
const uint16_t code_na029Times[] PROGMEM = {
  88, 90,
  88, 91,
  88, 181,
  177, 91,
  177, 8976,
};
const uint8_t code_na029Codes[] PROGMEM = {
  0x0C,
  0x92,
  0x53,
  0x46,
  0x16,
  0x49,
  0x29,
  0xA2,
  0xC0,
};
const struct IrCode code_na029Code PROGMEM = {
  freq_to_timerval(35842),
  22,		// # of pairs
  3,		// # of bits per index
  code_na029Times,
  code_na029Codes
};

/* Duplicate timing table, same as na009 !
 const uint16_t code_na030Times[] PROGMEM = {
 	53, 56,
 	53, 171,
 	53, 3950,
 	53, 9599,
 	898, 451,
 	900, 226,
 };
 */
const uint8_t code_na030Codes[] PROGMEM = {
  0x80,
  0x00,
  0x41,
  0x04,
  0x12,
  0x08,
  0x20,
  0x00,
  0x00,
  0x04,
  0x92,
  0x49,
  0x2A,
  0xBA,
  0x00,
};
const struct IrCode code_na030Code PROGMEM = {
  freq_to_timerval(38462),
  38,		// # of pairs
  3,		// # of bits per index
  code_na009Times,
  code_na030Codes
};
const uint16_t code_na031Times[] PROGMEM = {
  88, 89,
  88, 90,
  88, 179,
  88, 8977,
  177, 90,
};
const uint8_t code_na031Codes[] PROGMEM = {
  0x06,
  0x12,
  0x49,
  0x46,
  0x32,
  0x61,
  0x24,
  0x94,
  0x60,
};
const struct IrCode code_na031Code PROGMEM = {
  freq_to_timerval(35842),
  24,		// # of pairs
  3,		// # of bits per index
  code_na031Times,
  code_na031Codes
};

/* Duplicate timing table, same as na009 !
 const uint16_t code_na032Times[] PROGMEM = {
 	53, 56,
 	53, 171,
 	53, 3950,
 	53, 9599,
 	898, 451,
 	900, 226,
 };
 */
const uint8_t code_na032Codes[] PROGMEM = {
  0x80,
  0x00,
  0x41,
  0x04,
  0x12,
  0x08,
  0x20,
  0x80,
  0x00,
  0x04,
  0x12,
  0x49,
  0x2A,
  0xBA,
  0x00,
};
const struct IrCode code_na032Code PROGMEM = {
  freq_to_timerval(38462),
  38,		// # of pairs
  3,		// # of bits per index
  code_na009Times,
  code_na032Codes
};
const uint16_t code_na033Times[] PROGMEM = {
  40, 43,
  40, 122,
  40, 5297,
  334, 156,
  336, 155,
};
const uint8_t code_na033Codes[] PROGMEM = {
  0x60,
  0x10,
  0x40,
  0x04,
  0x80,
  0x09,
  0x00,
  0x00,
  0x00,
  0x00,
  0x10,
  0x00,
  0x20,
  0x82,
  0x00,
  0x20,
  0x00,
  0x00,
  0x0A,
  0x00,
  0x41,
  0x00,
  0x12,
  0x00,
  0x24,
  0x00,
  0x00,
  0x00,
  0x00,
  0x40,
  0x00,
  0x82,
  0x08,
  0x00,
  0x80,
  0x00,
  0x00,
  0x00,
};
const struct IrCode code_na033Code PROGMEM = {
  freq_to_timerval(38462),
  100,		// # of pairs
  3,		// # of bits per index
  code_na033Times,
  code_na033Codes
};

/* Duplicate timing table, same as na004 !
 const uint16_t code_na034Times[] PROGMEM = {
 	55, 57,
 	55, 170,
 	55, 3949,
 	55, 9623,
 	56, 0,
 	898, 453,
 	900, 226,
 };
 */
const uint8_t code_na034Codes[] PROGMEM = {
  0xA0,
  0x00,
  0x41,
  0x04,
  0x92,
  0x08,
  0x24,
  0x92,
  0x48,
  0x00,
  0x00,
  0x01,
  0x2B,
  0x3D,
  0x00,
};
const struct IrCode code_na034Code PROGMEM = {
  freq_to_timerval(38462),
  38,		// # of pairs
  3,		// # of bits per index
  code_na004Times,
  code_na034Codes
};
const uint16_t code_na035Times[] PROGMEM = {
  96, 93,
  97, 93,
  97, 287,
  97, 3431,
};
const uint8_t code_na035Codes[] PROGMEM = {
  0x16,
  0x66,
  0x5D,
  0x59,
  0x99,
  0x50,
};
const struct IrCode code_na035Code PROGMEM = {
  freq_to_timerval(41667),
  22,		// # of pairs
  2,		// # of bits per index
  code_na035Times,
  code_na035Codes
};
const uint16_t code_na036Times[] PROGMEM = {
  82, 581,
  84, 250,
  84, 580,
  85, 0,
};
const uint8_t code_na036Codes[] PROGMEM = {
  0x15,
  0x9A,
  0x9C,
};
const struct IrCode code_na036Code PROGMEM = {
  freq_to_timerval(37037),
  11,		// # of pairs
  2,		// # of bits per index
  code_na036Times,
  code_na036Codes
};
const uint16_t code_na037Times[] PROGMEM = {
  39, 263,
  164, 163,
  514, 164,
};
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
void loop() {
  
  sendAllCodes();
  sleepNow();
  // if the user pushes the Trigger button and lets go, then start transmission of all POWER codes
  if (digitalRead(TRIGGER) == 0) {
    delay_ten_us(3000);  // delay 30ms
    if (digitalRead(TRIGGER) == 1) {
      sendAllCodes();
    }
  }
}


/****************************** LED AND DELAY FUNCTIONS ********/


// This function delays the specified number of 10 microseconds
// it is 'hardcoded' and is calibrated by adjusting DELAY_CNT
// in main.h Unless you are changing the crystal from 8mhz, dont
// mess with this.
void delay_ten_us(uint16_t us) {
  uint8_t timer;
  while (us != 0) {
    // for 8MHz we want to delay 80 cycles per 10 microseconds
    // this code is tweaked to give about that amount.
    for (timer=0; timer <= DELAY_CNT; timer++) {
      NOP;
      NOP;
    }
    NOP;
    us--;
  }
}


// This function quickly pulses the visible LED (connected to PB0, pin 5)
// This will indicate to the user that a code is being transmitted
void quickflashLED( void ) {
  digitalWrite(LED, HIGH);
  delay_ten_us(3000);   // 30 millisec delay
  digitalWrite(LED, LOW);
}

// This function just flashes the visible LED a couple times, used to
// tell the user what region is selected
void quickflashLEDx( uint8_t x ) {
  quickflashLED();
  while(--x) {
    delay_ten_us(15000);     // 150 millisec delay between flahes
    quickflashLED();
  }
}




/****************************** SLEEP and WAKE FUNCTIONS ********/
// from kaqkjz:
// http://www.ka1kjz.com/561/adding-sleep-to-tv-b-gone-code/

void sleepNow()
{
  set_sleep_mode(TRIGGER);                    // sleep mode is set here

  sleep_enable();                             // enables the sleep bit in the mcucr register

  attachInterrupt(0, wakeUpNow, LOW);         // use interrupt 0 (pin 2) and run function
  // wakeUpNow when pin 2 gets LOW

  sleep_mode();                               // here the device is actually put to sleep!!
  // THE PROGRAM CONTINUES FROM HERE ON WAKE

  sleep_disable();                            // first thing after waking, disable sleep

  detachInterrupt(0);                         // disables int 0 as the wakeupnow code will
                                              // not be executed during normal runtime
}

void wakeUpNow()
{
  // any needed wakeup code can be placed here
}

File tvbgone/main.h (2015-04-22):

#include <avr/pgmspace.h>


// The TV-B-Gone for Arduino can use
//   either the EU or the NA database of POWER CODES
// EU is for Europe, Middle East, Australia, New Zealand, and some countries in Africa and South America
// NA is for North America, Asia, and the rest of the world not covered by EU

// Two regions!
#define NA 1
#define EU 0

// What pins do what
#define DBG 12
#define LED 13
#define IRLED 10
#define TRIGGER 2
#define REGIONSWITCH 5

// Lets us calculate the size of the NA/EU databases
#define NUM_ELEM(x) (sizeof (x) / sizeof (*(x)));

// set define to 0 to turn off debug output
#define DEBUG 0
#define DEBUGP(x) if (DEBUG == 1) { x ; }

// Shortcut to insert single, non-optimized-out nop
#define NOP __asm__ __volatile__ ("nop")

// Tweak this if neccessary to change timing
#define DELAY_CNT 25

// Makes the codes more readable. the OCRA is actually
// programmed in terms of 'periods' not 'freqs' - that
// is, the inverse!
#define freq_to_timerval(x) (F_CPU / 8 / x - 1)

// The structure of compressed code entries
struct IrCode {
  uint8_t timer_val;
  uint8_t numpairs;
  uint8_t bitcompression;
  uint16_t const *times;
  uint8_t const*codes;
};

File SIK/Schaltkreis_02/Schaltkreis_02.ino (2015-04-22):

/*
SparkFun Inventors' Kit
Beispiel Sketch 02

Potentiometer

  Miss die Position eines Potentiometers und benutze diese, um die 
  Blinkgeschwindigkeit einer LED zu steuern.
  Dreh den Griff, um sie schneller oder langsamer blinken zu lassen.
  
  Was ist ein Potentiometer?
  
  Ein Potentiometer, oder "Poti" abgekürzt, ist ein Drehregler.
  Das ist die Art von Steuerung, die man in Lautstärkereglern oder
  Dimmern für Lampen findet. Ein Potentiometer verändert den Widerstand,
  wenn dein Drehknopf gedreht wird. Benutzt man es als Spannungsteiler,
  kann der Arduino die Postion des Drehknopfs erkennen, und diesen Wert
  benutzen, um alles mögliche zu steuern (zum Beispiel die Blinkgeschwin-
  digkeit einer LED, wie wir es hier tun).
  
  Hardware-Verbindungen:
    
    Potentiometer:
    
      Potentiometer haben drei Pins. Wenn wir eines als Spannungsteiler
      benutzen, verbinden wir die äußeren Pins mit Spannung (Vcc) und 
      Masse(GND). Der mittlere Pin wird zum Signalausgang (eine Spannung, 
      die zwischen 0 Volt und 5 Volt variiert, abhängig von der Postion 
      des Einstellknopfs).
      
      Verbinde den mittleren Pin mit ANALOG IN Pin A0 am Arduino.
      Verbinde einen der äußeren Pins mit 5V.
      Verbinde den anderen äußeren Pin mit GND.
      
      (TIP: wenn dein Programm läuft und sich die Drehrichtung des Potis
      „verkehrt herum“ anfühlt, kannst du die 5V- und GND-Anschlüsse
      am Poti vertauschen, um die Richtung zu ändern.)
      
    LED:
      
      Die meisten Arduinos haben bereits eine LED und VorWiderstand, die 
      mit Pin 13 verbunden sind, also kann es sein, dass du keine zusätz-
      lichen Schaltung brauchst.

      Möchtest du allerdings eine weitere LED an Pin 13 aschließen, oder 
      einen anderen Pin benutzen, befolge diese Schritte:
      
        Verbinde die postitive Seite deiner LED (längeres Beinchen) mit 
        dem Arduino Digital-Pin 13 (oder einem anderen, digitalen Pin, 
        aber vergiss nicht, den Code so zu ändern, dass sie übereinstimmen).
        
        Verbinde die negative Seite deiner LED (kürzeres Beinchen) mit 
        einem 330-Ohm-Widerstand (orange-orange-braun).
        
        Verbinde die andere Seite des Widerstands mit GND.

Dieser Entwurf wurde ursprünglich von SparkFun Electronics mit viel Hilfe
der Arduino-Community geschrieben.
Übersetzt von den WissenSchaffern der Universität Ulm
Besuche http://learn.sparkfun.com/products/2 für Informationen über das SIK.
Besuche http://www.arduino.cc um mehr über den Arduino zu lernen.

Version 2.0 6DE/2015
*/  


// Willkommen zurück! In diesem Entwurd werden wir anfangen, 
// "Variablen" zu benutzen.

// Eine Variable ist eine benannte Zahl. Wir benutzen diese oft, um
// Zahlen zu speichern, die sich ändern – zum Beispiel Messungen aus
// der Außenwelt, oder um einen Entwurf verständlicher zu machen 
// (manchmal macht ein bezeichnender Name mehr Sinn, als eine Zahl 
// anzustarren).

// Variablen können verschiedenen "Datentypen" sein, die wir benutzen 
// werden (darf sie negativ sein? Ein Komma haben?)  Wir werden später
// mehr Datentypen einführen, aber im Moment bleiben wir bei der guten
// alten Ganzzahl – der "Integer" ("int").

// Integer sind ganze Zahlen (0, 3, 5643). Sie können negativ sein, 
// und aus Gründen, die wir jetzt nicht weiter auführen, können sie 
// einen Wert zwischen -32768 und 32767 haben. (Keine Sorge, falls du
// größere Zahlen brauchst, gibt es dafür andere Datentypen. Siehe: 
// http://arduino.cc/en/Reference/VariableDeclaration für eine Liste
// aller Datentypen, die du benutzen kannst).

// Du musst Variablen "deklarieren" bevor du sie benutzt, damit der
// Computer sie kennt.
// Hier deklarieren wir zwei Integer-Variabeln zugleich, und gleich-
// zeitig initalisieren wir sie mit genauen Werten. Wir machen das, 
// damit wir in Zukunft die Pins mit ihrem Namen, statt ihrer Nummer
// bezeichnen können. 

// Beachte, dass bei Variablennamen Groß-und Kleinschreibung zählt!
// Wenn du einen Fehler bekommst, dass eine Variable nicht deklariert
// sei, kontrolliere, ob du die Variablennamen korrekt geschrieben hast.

// Hier erzeugen wir eine Variable mit dem Namen "sensorPin" vom Typ 
// "int" und initalisieren sie mit dem Wert "0":

int sensorPin = 0;  //Das Potentiomete ist mit dem Analogen Pin 0 verbunden


int ledPin = 13;    //Die LED ist mit dem digitalen Pin 13 verbunden

// Eine Sache noch. Wenn du eine Variable außerhalb einer Funktion
// deklarierst, so wie hier, heißen sie "globale Variablen" und 
// können von allen Funktionen gesehen werden.
// Normalerweise ist es sinnvoll, die Gültigkeit einer Variable auf
// einzelne Funktionen einzuschränken – aber da wir gerade erst an-
// fangen, reichen globale Variablen voll aus.
 
void setup()   //diese Funktion wird ausgeführt, sobald der Sketch läuft
{
  // Wir benutzen Pin 13, um die LED anzusteuern – also müssen wir ihn 
  // als Ausgang konfigurieren.
  
  // Da wir bereits eine Variable mit dem Namen ledPin auf Pin 13
  // gesetzt haben, können wir "ledPin" anstatt Pin 13 benutzen.
  // Dies macht den Code übersichtlicher.
  
  pinMode(ledPin, OUTPUT);
  
  // Diese Zeile macht dasselbe wie "PinMode(13, OUTPUT);"
  
  // Du wunderst dich vielleicht, warum wir nicht den sensorPin als 
  // Eingang einrichten. Der Grund dafür ist, dass dies ein analoger
  // Eingang ist. Diese Pins haben die besondere Fähigkeit, verschie-
  // dene Spannungen von Sensoren wie unserem Potentiometer einzulesen.
  // Da sie immer als Eingänge benutzt werden, müssen sie nicht wei-
  // ter konfiguriert werden.
}
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

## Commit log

2015-08-26 added revision 2 of the board
    This revised version of the uulmduino board should fix the following issues:
    * correct polarity for DC jack
    * TV-B-Gone-Input wired to Pin 10 instead of Pin 9
    * larger NPTH for battery holder strain relief
    [uulmduino-20150323.kicad_pcb, uulmduino_v02.sch, uulmduino_v2_20150826.kicad_pcb]
2015-11-16 Errata ergaenzt, BOM hinzugefuegt
    Fehler in Rev 2: Transistor-Footprint falsch ;(
    [uulmduino_v2_20150826.kicad_pcb]
2015-11-25 Fixed omissions in BOM, clarified descriptions in handbook
2015-11-25 Re-rendered PDF for manual; BOM extended
2015-12-02 reorganized arduino INO files for compatibility w/ IDE
2020-07-15 updated link to ateval board
